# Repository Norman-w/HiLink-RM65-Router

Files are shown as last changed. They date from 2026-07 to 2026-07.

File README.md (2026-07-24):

# HiLink RM65 — 家用 WiFi 行为管理路由研究

基于海凌科 **HLK-RM65**（MT7981B + MT7976C + MT7531A，Wi‑Fi 6 AX3000 / 联发科方案）的自研路由可行性评估。  
（早期曾评估 RM68 高通方案，相关资料保留在 `docs/`、`firmware/` 供对照。）

## 结论摘要

| 问题 | 结论 |
|---|---|
| 能媲美家用 AX3000 WiFi 吗？ | **硬件档位可以**；天线/固件卸载/结构做好后接近同级成品 |
| 只适合研究吗？ | **否**；规格定位含家用路由/Mesh/网关 |
| 适合重度行为管理吗？ | **单独不够**（256MB + 双 A53）；策略建议上移 |
| Mac mini + AP 怎样？ | **算力与策略远强**；WiFi 靠专业 AP，勿用 Mac 内置无线当主 AP |

详见：

- [docs/评估报告-家用WiFi行为管理可行性.md](docs/评估报告-家用WiFi行为管理可行性.md)
- [docs/架构-MAC分流旁路分析.md](docs/架构-MAC分流旁路分析.md) — RM68 轻转发 + MacBook 旁路分析

## 资料

### HLK-RM65（主资料）

官方下载页：https://h.hlktech.com/Mobile/download/FDetail/257.html  
清单：`docs/download-manifest-rm65.json`

| 文件 | 说明 |
|---|---|
| `docs/HLK-RM65-规格书-V1.31.pdf` | 产品规格书 |
| `docs/HLK-RM65结构器件规格书.zip` | BTB / 产品图 / 表贴螺柱 |
| `docs/RM65封装尺寸.pdf` | 模组封装尺寸 |
| `docs/HLK-RM65尺寸图.png` | 尺寸图（含安装孔标注） |
| `docs/HLK-RM65-KIT-V1.0.zip` | 开发套件原理图与 PCB |
| `docs/HLK-RM65-KIT-V1.0-原理图.pdf` | KIT 原理图 PDF |
| `docs/HLK-RM65-KIT-Dimension.PcbDoc.zip` | KIT 尺寸标注 PCB（外壳开孔关键） |
| `docs/RM65编译资料.pdf` | 编译资料 |
| `docs/extracted/` | 已解压与文本提取 |

### HLK-RM68（对照保留）

官方下载页：https://h.hlktech.com/Mobile/download/FDetail/348.html

| 文件 | 说明 |
|---|---|
| `docs/HLK-RM68-规格书-V1.02.pdf` | 产品规格书 |
| `docs/HLK-RM68-结构件规格书.zip` | BTB / 屏蔽罩 / 散热片 |
| `docs/HLK-AX3000-KIT-V1.0.zip` | 开发套件原理图与 PCB |
| `firmware/README.md` | OpenWrt/SDK 下载与刷机说明 |

固件 SDK（百度）：https://pan.baidu.com/s/10omz47I9bUNruT9euDZYHQ?pwd=a9pu （`rm68-master.tar.gz` ≈3.07GB）

## 推荐架构（行为管理）

```
光猫 → Mac mini / N100（策略网关）→ 交换机 → AP（商业 AP 或 RM65 AP 模式）
```

轻量一体方案：光猫 → RM65（OpenWrt + DNS/防火墙级管控）。

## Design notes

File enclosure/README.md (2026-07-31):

# HLK-AX3000-KIT V1.0 参数化外壳

本目录是基于官方 `HLK-AX3000-KIT.PcbDoc`、到货板实测和实物照片重构的
可打印版本。板框、四个安装孔和接口 XY 采用官方数据；接口 Z、高度、外伸量、
散热片和底部焊脚净空采用用户对到货板的实测值。

## 交付文件

- `rm65_kit_enclosure.scad`：参数化主模型（含尺寸与装配断言）。
- `rm65_kit_antenna.scad`：天线孔/螺母槽/理线桥（由主文件 include）。
- `rm65_kit_shell_parts.scad`：立柱、脚垫、接口切口等共用模块。
- `build/rm65_kit_bottom.stl`：底壳，正常方向打印。
- `build/rm65_kit_top.stl`：顶壳，已自动翻转到打印方向。
- `build/rm65_kit_foot_pad.stl`：单个 TPU 脚垫，打印 4 个。
- `build/rm65_kit_top_assembly.stl`：HTML 装配预览专用，不作为打印件。
- `preview.html`：合盖、爆炸、接口和天线装配预览。
- `INTERFACE_AUDIT.md`：官方坐标与实测值审计记录。

## 已落实的尺寸

- PCB：`152.0038 × 109.0000 × 1.6 mm`。
- PCB 底面：壳底内表面上方 `4.0 mm`；可容纳约 `2.5 mm` 焊脚并留
  `1.5 mm` 余量。
- PCB 顶面：壳体坐标 `Z=8.0 mm`。
- 顶部净空：散热片自 PCB 顶面 `17 mm`，另留 `2.5 mm`。
- 外壳壁/底/顶厚：`2.4 mm`；PCB 到前/右内壁通道 `3.5 mm`。
- 左侧（杜邦座 / 网口背面）增加 `20.0 mm` 主天线装配舱；后侧仍保留
  `20.0 mm` 舱与原 5 口。外形约 `183.804 × 140.800 × 29.900 mm`。

官方四孔均为 `3.175 mm` 实体孔，板左下为坐标原点：

| 位号 | X (mm) | Y (mm) |
|---|---:|---:|
| J8 | 4.0008 | 4.0053 |
| J5 | 3.9879 | 105.0016 |
| J6 | 148.3238 | 4.0000 |
| J7 | 148.3238 | 105.0000 |

每个底壳 PCB boss 有平整承托面、`2.85 mm` 导向凸台和 `1.7 mm` M2
自攻 pilot。PCB 固定与上下壳固定是两套独立紧固件，不能共用。

## 接口开口

- 右侧：六个 RJ45 的金属壳几乎连续，使用一个连续贯穿窗口，不打印口间肋。
  RJ45 自 PCB 顶面高 `13.8 mm`、向外 `2.0 mm`，窗口上下各留 `0.4 mm`。
- 下侧：`GPIO_RST`、`SYS_RST` 两个 `3.2 mm` 细工具孔，外侧有 `6 mm`
  浅凹导向；按钮高 `4.5 mm`、向外 `0.5 mm`。
- 下侧：USB-A 从 PCB 顶面 `0.5–8.0 mm`，向外 `2.5 mm`；中心
  `X=51.0 mm`（实物尺测外口 `X=43.5–58.5 mm`）；开口
  `15.6 × 8.3 mm`，对应打印边界 `X=43.2–58.8 mm`。官方 PcbDoc
  的 `X=38.40 mm` 是封装/3D 模型插入原点，不是 USB 金属口中心。
- 下侧：12 V DC 座贴 PCB，高 `10.8 mm`、向外 `1.2 mm`；开口直径
  `11.4 mm`。壳外应保留约 `18 mm` 插头握持空间和 `35 mm` 线缆弯折空间。
- 左侧：USB-TTL Type-C 贴 PCB，高 `3.0 mm`、向外 `0.8 mm`；开口
  `10.0 × 3.8 mm`，隧道加深穿过左侧 `20 mm` 天线装配舱到达板载口。旧版
  误用了封装参考点 Y=`19.1213 mm`；官方封装外形宽 `8.636 mm`，修订后使用
  插口中心 Y=`14.7673 mm`。左侧维护针排保持封闭，不再开窗。
- 顶面靠后：九个 `3.6 mm` LED 窗，各自带 `5.4 mm` 外径的垂直隔光导管；
  建议插入 3 mm 透明导光棒或光纤，长度按打印件与 LED 的实际距离修剪。

接口前的 3.5 mm 空腔是插头通道，不是额外挡板。Type-C、USB、DC 和 RJ45
公头均从外侧窗口穿过该通道插入板载母座。
侧面接口布尔切口会继续延伸穿过顶壳定位裙边；RJ45、USB-A、DC、两个
Reset 工具孔和 Type-C 的插入路径内不会残留裙边薄片。接口以外的裙边仍保留，
用于上下壳定位和承受横向载荷。

## 天线结构

共 10 个 M6 座（后 5 + 左 5），套餐只拧 **5 根**：2.4G×2 + 5G×3。
IPX 够得着**后壁左三孔 + 左侧任意孔**；后壁右两孔留空。推荐座与倾角见
`INTERFACE_AUDIT.md` RF 表（预览「RF五天线方案」：蓝=2.4G，橙=5G，灰座=空）。

每个安装位包括：

- `6.5 mm` M6 圆形贯穿孔（M6 螺纹另留 `0.5 mm` FDM 余量）；
- 外侧 `1.0 mm` 深、Ø9 面沉，使外丝多探出约 1 mm，胶棒天线更易拧紧；
- 内侧 `8.3 mm` 对边、深 `3.2 mm` 的六角螺母槽；
- `13 × 12 mm` 内侧加厚区，底边严格止于上下壳分型面；
- 独立馈线固定桥；左/后舱按 `23 mm` 穿装包络预留。

用户实测螺纹为 M6；六角螺母边长约 `4.6 mm`、厚约 `3 mm`，折算对边约 `7.97 mm`；
默认 `8.3 mm` 螺母槽包含 FDM 装配余量。不同打印机的孔收缩不同，正式长印
前建议只切片/打印一个天线孔和螺母槽局部小样；若过紧，调整
`antenna_hole_diameter` 或 `antenna_nut_across_flats`，不要强压。

## 紧固件与脚垫

- PCB：`4 × M2×6` 盘头自攻螺钉，锁入底壳 `1.7 mm` pilot。
- 合盖：推荐 `4 × M2×20` 沉头螺钉，从外底面进入，锁入顶壳 boss。默认沉头大口
  `5.0 mm`、深 `1.8 mm`，大口朝外、向内收窄到 `2.3 mm`。螺钉长度按
  实际打印后的有效牙深选配；M2×20 约有 4 mm 的顶壳有效啮合。
- 脚垫：`rm65_kit_foot_pad.stl` 打印 4 个，推荐 TPU 95A。底壳槽直径
  `11.0 mm`、入口 `11.4 mm`、深 `1.0 mm`；脚垫直径 `11.2 mm`、总高
  `3.2 mm`，约 `2.2 mm` 外露。四槽与四个沉头工具通道完全错开。

顶壳和底壳合盖 boss 均有直接连接壳壁/壳顶的加强肋。底壳通孔柱止于
`Z=16 mm` 分型面，顶壳受牙柱从同一分型面向顶盖延伸；顶壳肋只位于壳内，
不会伸入底壳或与其干涉。顶壳内裙每侧保留 `0.30 mm` 配合间隙。
顶壳定位裙边根部另有连续环形斜肋：在 `4.0 mm` 高度内从分型定位条
向外缓慢展开，并嵌入顶壳侧壁 `0.60 mm`。裙边内侧保持竖直，不再向
壳内形成楔形尖角；分型面以下的外侧配合尺寸不变，因此仍保留原合盖间隙。

## 打印与预览

```sh
cd enclosure
./export_stl.sh
python3 server.py
```

浏览 `http://127.0.0.1:8080/preview.html`。Three.js 依赖从 unpkg 加载，首次
打开需联网。默认显示真实闭合装配；爆炸视图中的 PCB、接口、螺钉、螺母、
馈线和天线是非打印装配说明，下载区只有壳体和 TPU 脚垫。

建议 FDM 参数：0.4 mm 喷嘴、0.2 mm 层高、4 道墙、顶底至少 5 层、
20–30% 填充。底壳外底面朝下；顶壳使用已翻转的 STL。顶壳文字
`NORMAN`（11.5 mm）/ `Router V1.2.0`（7.2 mm）是贯穿镂空，保留
1.0 mm 模板连桥；两行均在前侧（下侧接口上方），NORMAN 居中、版本靠右，
避开中央通风槽。

## 仍需在首次试装时关注的风险

现有资料已足够生成直接切片的 STL，不再缺少板卡坐标或接口高度。但以下是
打印工艺公差，不应伪装成官方尺寸：

1. Ø6.5 mm 圆孔、8.3 mm 六角槽、M2 pilot 和顶壳裙边会受材料收缩与孔补偿影响；
   先做局部小样或在切片器设置孔补偿。
2. LED 导光棒不是套餐 B 已知配件；不安装时仍可透光，但亮度和串光效果需
   实机上电确认。
3. 默认结构按 M2×20 沉头螺钉提供约 4 mm 啮合；不同螺头标准与打印 pilot
   松紧仍需装配前试配。
4. 12 V 适配器极性应按适配器标签确认；RM65 模块的 3.3 V 不是 KIT 的
   外部直供电压。

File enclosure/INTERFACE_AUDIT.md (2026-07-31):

# HLK-AX3000-KIT V1.0 接口与安装坐标审计

本表记录 `rm65_kit_enclosure.scad` 的数据来源。XY/四孔以官方 PcbDoc 为准；
Z、高度和外伸量来自用户对 `HLK-AX3000-KIT V1.0 241205` 到货板的实测。

## PCB 与安装孔

- 板框：`152.0038 × 109.0000 mm`。
- J8：`(4.0008, 4.0053) mm`。
- J5：`(3.9879, 105.0016) mm`。
- J6：`(148.3238, 4.0000) mm`。
- J7：`(148.3238, 105.0000) mm`。
- 四孔实体孔径：官方 `125 mil = 3.175 mm`；焊盘约 `5.08 mm`。

用户手测约 3 mm 孔径、距相邻板边约 3.5 mm，与肉眼/卡尺精度下的官方数据
相容；模型采用官方精确值，不再使用旧版 4 mm 对称猜值。

## 接口数据

| 接口 | 官方 PCB 相对坐标 | 实测 Z/外伸 | 壳体处理 |
|---|---|---|---|
| SW1 / GPIO_RST | X=11.29 | 高4.5，外伸0.5 | 3.2工具孔+6.0浅凹 |
| SW2 / SYS_RST | X=22.03 | 高4.5，外伸0.5 | 3.2工具孔+6.0浅凹 |
| USB-A / USB2 | 官方插入原点 X=38.40；实物口 X=43.5–58.5，中心 X=51.0 | Z=0.5–8.0，外伸2.5 | 15.6×8.3贯穿窗；实测口中心相对原点 +12.6 mm |
| 12V DC / J1 | X=99.95 | 贴板，高10.8，外伸1.2 | Ø11.4贯穿孔 |
| USB-TTL Type-C / USB1 | 参考 Y=19.1213；外形中心 Y=14.7673 | 贴板，高3.0，外伸0.8 | 10.0×3.8左侧窗；采用官方封装外形中心 |
| RJ45 ×6 | Y=15.64…91.74 | 贴板，高13.8，外伸2.0 | 一个连续窗口，无口间肋 |
| LED ×9 | Y=102.06；X=15.01…64.40 | 彩色灯帽朝上 | 顶面9个Ø3.6窗+独立导光管 |

RJ3 是四联口，RJ1/RJ2 为两个单口，物理共六口。用户照片确认金属外壳之间
几乎相贴，因此打印塑料隔肋既不符合实物又会形成脆弱薄壁，已改成连续窗。

左侧 JP1/JP2/JP3/JP4/JP7 维护针排保留在壳内；用户明确不需要外部访问，
模型不再开维护窗。USB-TTL Type-C 是左侧唯一外部服务开口。

## 高度基准

- PCB 下方最高焊脚约 `2.5 mm`；模型留 `4.0 mm`。
- PCB 厚 `1.6 mm`，模型 PCB 顶面在 `Z=8.0 mm`。
- 上方最高为散热片，自 PCB 顶面 `17 mm`；模型再留 `2.5 mm`，顶盖内表面
  在 `Z=27.5 mm`。
- 组件占位和壳体孔均由同一组参数派生，不再共用旧版猜测的全局 Z=13 mm。

## 天线与电源

套餐 B 含 5 根同规格 6 dB 胶棒天线、连接线和 12 V 1 A 适配器。实测天线
接头无防转平面；实物确认是 M6 螺纹，总长约 10 mm，装外部天线后余约 5 mm，
六角螺母厚约 3 mm、边长约 4.6 mm。模型采用 Ø6.5 mm 贯穿孔、8.3 mm 对边
六角槽和内侧加厚。首版试装还确认接头必须从内向外穿装。

IPX 馈线偏短：后壁**右侧两孔够不着**，可用范围为**后壁左侧三孔 + 左侧五孔**。
壳体仍打印 10 个 M6 座；套餐只装 **5 根**（2.4G×2 + 5G×3），其余座留空不拧。

### RF 装法（编译期校验间距）

| 角色 | 壁 | 坐标 (mm) | 姿态 | 备注 |
|---|---|---:|---|---|
| 2.4G-A | 左 | Y=34 | 竖直 | 避 Type-C |
| 2.4G-B | 后 | X=100 | 竖直 | IPX 可达最远后座；与 A 异面 |
| 5G-A | 后 | X=30 | 竖直，略外展约 20° | 后左角轻微外展即可 |
| 5G-B | 后 | X=65 | 竖直 | 与 5G-A 间距 35 mm |
| 5G-C | 左 | Y=90 | 竖直 | 靠孔距做分集，不必大倾角 |

留空：后壁 X≈139 / 172；左壁 Y=55 / 72 / 128。  
目标间距：2.4G 对 ≈146 mm（>λ/2≈62.5）；5G 互距 ≥35 mm（≥λ/2≈27.5 @5.5 GHz）。  
PCB 原点 `25.9, 5.9`；Type-C 隧道加深；天线孔外侧 `1.0 mm` 面沉（Ø9）。

原理图 J1 输入网络标注 `+4.5V~18V`；套餐适配器为 12 V 1 A。RM65 模块的
3.3 V 由底板转换，不是整套 KIT 的外部直供电压。适配器极性仍应以标签为准。

## 仍非官方定值的项目

- FDM 打印后的孔收缩、裙边配合和 M2 pilot 自攻松紧。
- LED 导光棒材质、长度、亮度及串光效果。
- 合盖默认 M2×20 沉头螺钉的螺头标准与自攻松紧。

这些属于打印/装配验证，不是板卡尺寸缺口；STL 可直接进入切片器，但正式长印
前仍推荐打印天线螺母槽和 M2 pilot 的局部试配件。

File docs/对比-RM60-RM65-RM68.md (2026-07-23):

# HLK-RM60 / RM65 / RM68 对比

> 依据海凌科公开产品页与规格书摘要（非实验室实测）。信号最终仍取决于天线与固件。

## 一览

| 项目 | **RM60** | **RM65** | **RM68** |
|---|---|---|---|
| 定位 | 入门 Wi‑Fi 6 路由模组 | 家用级 AX3000（联发科） | 家用级 AX3000（高通） |
| 芯片方案 | MT7621A + MT7905 + MT7975 | **MT7981B + MT7976C + MT7531A** | **IPQ5018 + QCA8337 + QCN6102** |
| Wi‑Fi 档位 | **AX1800**（约 573+1201 Mbps） | **AX3000**（574+2402 Mbps） | **AX3000**（574+2402 Mbps） |
| 5G 频宽 | 最高约 **80 MHz** | **160 MHz** | **160 MHz** |
| CPU | 双核 MIPS @ **880 MHz** | 双核 A53 @ **1.3 GHz** | 双核 A53 @ **1 GHz** + 12 线程网络协处理 |
| 内存 / Flash | **128 MB / 16 MB** | **256 MB / 128 MB NAND** | **256 MB / 128 MB NAND** |
| 网口 | 千兆 ×5 | 千兆 ×5~6，另有 **2.5G SGMII** 能力 | 千兆 ×6（1WAN+5LAN） |
| 外置 FEM | 常规方案 | 常规高性能 | 宣传 **外挂 4× FEM** |
| 供电 | 3.3V | 3.3V（建议 ≥5A） | **5V**（建议 ≥3.5A） |
| 工作温度 | 约 -20~60℃ | -20~80℃ | -20~80℃ |
| 软件 | OpenWrt | OpenWrt | OpenWrt |
| 尺寸 | 约 60×90 mm | 60×90 mm | 60×90 mm |

## 信号谁更强？

**标称无线能力：RM65 ≈ RM68 ≫ RM60。**

- RM60 是 AX1800，5G 无 160 MHz，天花板明显更低。  
- RM65 / RM68 同属 AX3000 + 160 MHz，理论峰值同级。  
- 规格书发射功率都在「家用路由」量级（约十几～二十多 dBm）；RM68 强调 4×FEM、RM65 2.4G 也可到 ~24 dBm 档——**纸面接近，实墙表现看天线与校准，不能只看型号判输赢**。  
- 若只比「模组射频档位」：**不要选 RM60 当主力覆盖**；RM65 与 RM68 同档，需实测。

## 算力 / 做分流小程序谁更合适？

| 维度 | 更强方 | 说明 |
|---|---|---|
| CPU 主频与通用算力 | **RM65** | 1.3 GHz A53，跑 OpenWrt 用户态更宽裕 |
| 路由硬件卸载潜力 | RM68（若固件带齐 NSS）/ RM65（Filogic 生态） | 主线 OpenWrt 上高通 IPQ50xx 卸载常不完整 |
| Flash 装软件包 | **RM65 / RM68** | RM60 仅 16 MB Flash，自定义包很容易装不下 |
| 社区 OpenWrt 成熟度 | **通常 RM65（MT7981）更省心** | 联发科 Filogic 在 OpenWrt 上更常见；RM68 要盯厂商 SDK/卸载 |
| 2.5G 上行扩展 | **RM65** | 有 2.5G SGMII；RM68 规格以千兆口为主 |
| 与 KIT/资料 | 各有套件 | 你当前仓库已集中 RM68 资料 |

对「RM68 轻分流 + Mac 旁路分析」：**三款都能做用户态控 nft 规则**；更稳妥量产候选往往是 **RM65（生态）或 RM68（你已选型）**；RM60 仅适合验证概念，Flash/性能偏紧。

## 能力排序（综合）

```
家用 Wi‑Fi 吞吐/覆盖潜力：  RM65 ≈ RM68  >>  RM60
OpenWrt 二次开发省心度：    RM65  ≥  RM68  >>  RM60
内存/装包空间：              RM65 ≈ RM68  >>  RM60
性价比/入门：                RM60（但能力最弱）
```

**一句话：要信号和家用体验选 RM65 或 RM68（同档 AX3000）；RM60 明显低一档。RM65 更偏联发科生态与主频；RM68 更偏高通 + 外挂 FEM，适合你已开始的资料与 KIT 路线。**

---

## 对另一 AI「RM68 信号更强 / 工业宽温」说法的核对

| 说法 | 准确性 | 依据 |
|---|---|---|
| 两者都是 AX3000，速率 574+2402 | ✅ 正确 | 双方规格一致 |
| RM68 = IPQ5018 + QCN6102，外挂 4×FEM | ✅ 正确 | RM68 规格书写明 |
| RM65 = MT7981B @ 1.3GHz，算力更强 | ✅ 大体正确 | 主频更高，跑插件更宽裕 |
| RM68 有 12 线程 NPU，高并发更稳 | ⚠️ **有条件** | 厂商 SDK/带 NSS 卸载时成立；**主线 OpenWrt 上 IPQ50xx 常缺完整 NSS**，优势可能消失 |
| RM65 是「内置功放」、极限功率必弱于 RM68 | ❌ **不准确** | 英文页亦提到 2.4/5G PA/LNA；RM65 标称 2.4G 可达 ~24.5dBm，RM68 规格约 +23dBm 档——**不能据此断定 RM68 信号必强** |
| RM68 工作温度 -40℃~85℃ 工业级 | ❌ **错误** | **规格书 V1.02：工作 -20℃~80℃**；-40~85 是**存储**温度。营销文案「宽温 -40~85」与规格书冲突，以规格书为准 |
| RM65 工作 -20~80℃ | ✅ 与公开页一致 | 与 RM68 **工作温区同档** |
| 供电 3.3V/5A vs 5V/3.5A | ✅ 正确 | 底板电源设计不同 |

**结论：另一 AI 的芯片与算力侧写大体可用；「RM68 信号必然更强」「工业级 -40℃ 工作」不可采信。选型不能只靠 FEM 叙事。**

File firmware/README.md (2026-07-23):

# HLK-RM68 OpenWrt 固件说明

> 官方**没有**在下载中心直接挂 `.img`；固件在厂商 Gitee 指向的百度网盘 **SDK** 内，需编译生成，或向卖家索取现成 `nand-ipq5018-single.img`。

## 官方软件源

| 来源 | 链接 |
|---|---|
| Google Drive（资料 + 软件索引） | https://drive.google.com/drive/folders/1cPfJ_ET9kue43kTUIWVMKmQjL_faICfI |
| Gitee 刷机/编译说明 | https://gitee.com/shenyachuan/rm68 |
| **SDK 百度网盘（20250621）** | https://pan.baidu.com/s/10omz47I9bUNruT9euDZYHQ?pwd=a9pu （提取码 `a9pu`） |

百度网盘内实际文件（已核对）：

```text
20250621/rm68-master.tar.gz   ≈ 3.07 GB   （完整 QSDK，不是现成 .img）
```

目标刷机文件名（**需自行编译**后得到）：

```text
nand-ipq5018-single.img
```

路径（SDK 编译完成后）：`rm68-master/common/build/bin/nand-ipq5018-single.img`

**不要**刷其它机型的 IPQ5018 通用固件（分区/射频不同，易变砖）。  
网盘无现成可刷 `.img`；最快路径是：登录百度下载 SDK，或直接问店铺客服要 `nand-ipq5018-single.img`。

## 默认账号（厂商说明）

| 入口 | 地址/账号 | 密码 |
|---|---|---|
| Web | `http://192.168.1.1` | `admin` |
| SSH | `root` | `admin` |
| 串口 | 115200 8N1 | — |

（规格书曾写空密码；以 Gitee README 的 `admin` 为准，以实机为准。）

## 刷机方式 A：U-Boot + TFTP（推荐首次）

1. 电脑有线网卡静态 IP：`192.168.16.112`  
2. 网线接 RM68 底板 **WAN**  
3. TFTPd 根目录指向含 `nand-ipq5018-single.img` 的文件夹  
4. 串口上电，出现 `Hit any key to stop autoboot` 时按键进入 U-Boot  
5. 执行：

```sh
setenv ipaddr 192.168.16.123
setenv serverip 192.168.16.112
setenv bootargs console=ttyMSM0,115200n8
tftpboot nand-ipq5018-single.img
imgaddr=$fileaddr && source $imgaddr:script
```

图示见本目录 `gitee-rm68/image/`。

## 刷机方式 B：系统内 sysupgrade

设备已能 SSH 时：

```sh
# 本机
scp nand-ipq5018-single.img root@192.168.1.1:/tmp/

# 设备上
cd /tmp
sysupgrade nand-ipq5018-single.img
```

## 本仓库已缓存

- `HLK-RM68-drive/`：Drive 上的规格/结构件 + `software reference link.docx`  
- `gitee-rm68/`：官方刷机说明与截图  
- `RM68-SDK-README.md`：README 副本  

**预编译 `.img` 需你从百度网盘下载 SDK 后编译，或向海凌科/店铺客服要现成镜像。** 自动化环境无法绕过百度网盘登录验证码。

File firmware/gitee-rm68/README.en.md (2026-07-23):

# RM68

#### Description
rm68仓库，sdk太大，无法上传到git 
只有一个百度云盘的连接 ，SDK如果有更新会更换连接

#### Software Architecture
Software architecture description

#### Installation

1.  xxxx
2.  xxxx
3.  xxxx

#### Instructions

1.  xxxx
2.  xxxx
3.  xxxx

#### Contribution

1.  Fork the repository
2.  Create Feat_xxx branch
3.  Commit your code
4.  Create Pull Request

#### Gitee Feature

1.  You can use Readme\_XXX.md to support different languages, such as Readme\_en.md, Readme\_zh.md
2.  Gitee blog [blog.gitee.com](https://blog.gitee.com)
3.  Explore open source project [https://gitee.com/explore](https://gitee.com/explore)
4.  The most valuable open source project [GVP](https://gitee.com/gvp)
5.  The manual of Gitee [https://gitee.com/help](https://gitee.com/help)
6.  The most popular members  [https://gitee.com/gitee-stars/](https://gitee.com/gitee-stars/)

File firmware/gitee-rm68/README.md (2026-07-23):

# RM68

#### 介绍

#### SDK压缩包链接地址

20250621：
    通过网盘分享的文件：20250621
    链接: https://pan.baidu.com/s/10omz47I9bUNruT9euDZYHQ?pwd=a9pu 提取码: a9pu
#### 编译环境搭建

### 系统

SDK 编译环境 使用ubuntu16.04 其他版本不支持
ubuntu16.04下载地址：
    https://releases.ubuntu.com/16.04/ubuntu-16.04.7-desktop-amd64.iso
使用 virtualbox 安装
### 安装编译环境

sudo apt-get install gcc g++ binutils patch bzip2 flex make gettext pkg-config unzip zlib1g-dev libc6-dev subversion libncurses5-dev gawk sharutils curl libxml-parser-perl python-yaml ocaml-nox ocaml ocaml-findlib libssl-dev libfdt-dev  device-tree-compiler u-boot-tools autoconf libc6-i386  libgl1-mesa-dri:i386 mtd-utils libfdt-dev vim samba openssh-server git subversion flex make cmake quilt

### 编译
    tar xvf rm68-master.tar.gz     #默认解压到rm68-master目录下
    cd rm68-master/qsdk
    make V=s -j5
### 生成固件
    编译完成后， 需要使用命令 生成固件

    cd rm68-master/    #注意 执行命令前 需要进入到 SDK的根目录下
    mkdir -p common/build/ipq
    mkdir -p apss_proc/out/meta-scripts
    cp qsdk/qca/src/u-boot-2016/tools/pack.py apss_proc/out/meta-scripts/pack_hk.py
    sed -i 's#</linux_root_path>#/</linux_root_path>#' contents.xml
    sed -i 's#</windows_root_path>#\\</windows_root_path>#' contents.xml
    cp qsdk/bin/ipq/openwrt* common/build/ipq
    cp -r apss_proc/out/proprietary/QSDK-Base/meta-tools apss_proc/out/
    cp -rf qsdk/bin/ipq/dtbs/* common/build/ipq/
    cp -rf skales/* common/build/ipq
    cp -rf wlan_proc/build/ms/bin/5018.wlanfw.eval/* common/build/ipq/
    cp -rf wlan_proc/build/ms/bin/5018.wlanfw2.map_spruce_eval/* common/build/ipq/
    cp -rf wlan_proc/build/ms/bin/5018.wlanfw2.map_spr_spr_eval_cs/* common/build/ipq/
    cp -rf btfw_proc/out/IPQ5018/bin/FW_IMAGES/bt_fw_patch_* common/build/ipq
    cp qsdk/staging_dir/host/bin/ubinize common/build/ipq/
    cd common/build/
    sed "s/'''$/\n'''/g" -i update_common_info.py
    sed -i "s/os.chdir(ipq_dir)//" update_common_info.py
    sed -i -e '/update_common_info.py: 16M debug/,+5d' update_common_info.py
    sed '/packages/d;/"ipq5018_64"/d;/t32/d;/ret_prep_64image/d;/Required/d;/skales/d; /nosmmu/d;/os.system(cmd)/d;/os.chdir(ipq_dir)/d;/atfdir/d;/noac/d;/singleatf/d;/bl31.mbn/d;/bin_atf/d;/ret_pack_64image/d;/list_out_64_single/d;/list_out_64_apps/d;/dict_64_bit_single/d;/dict_64_bit_apps/d;/list_out_debug/d' -i update_common_info.py
    export BLD_ENV_BUILD_ID=LM256;python update_common_info.py

    执行完成后，会在common/build/bin 目录下生成几个文件
    其中nand-ipq5018-single.img 是匹配我们的硬件的固件

### 升级
    升级有两种方式
## 通过uboot升级
    在uboot下升级
    环境准备：
        电脑需要设置静态IP ： 192.168.16.112
        电脑的网口接RM68底板的WAN口
        电脑打开tftpd软件，目录选择文件nand-ipq5018-single.img所在目录
    RM68底板的调试串口位置：
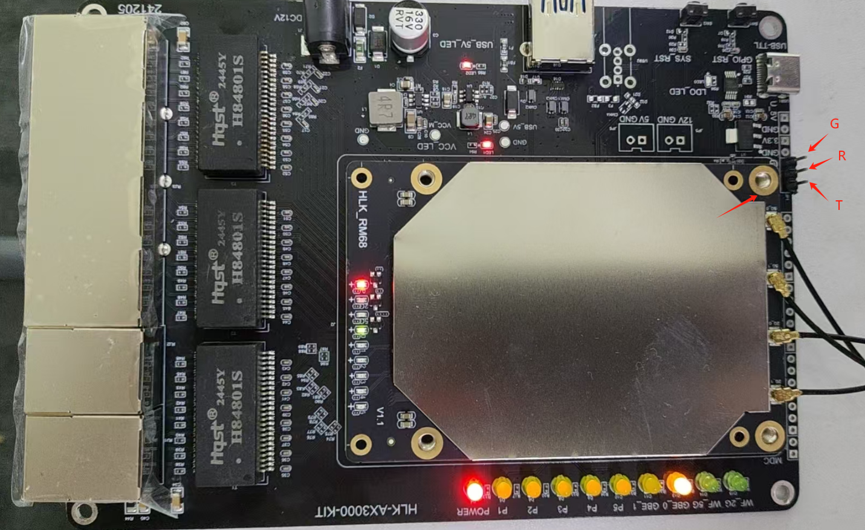
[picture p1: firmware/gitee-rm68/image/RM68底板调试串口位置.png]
底板串口位置

    默认串口波特率 ： 115200

    这里通过mobaxterm 终端工具演示：
    上电启动 在 串口输出 Hit any key to stop autoboot 倒计时时 按任意键 进入到uboot命令行
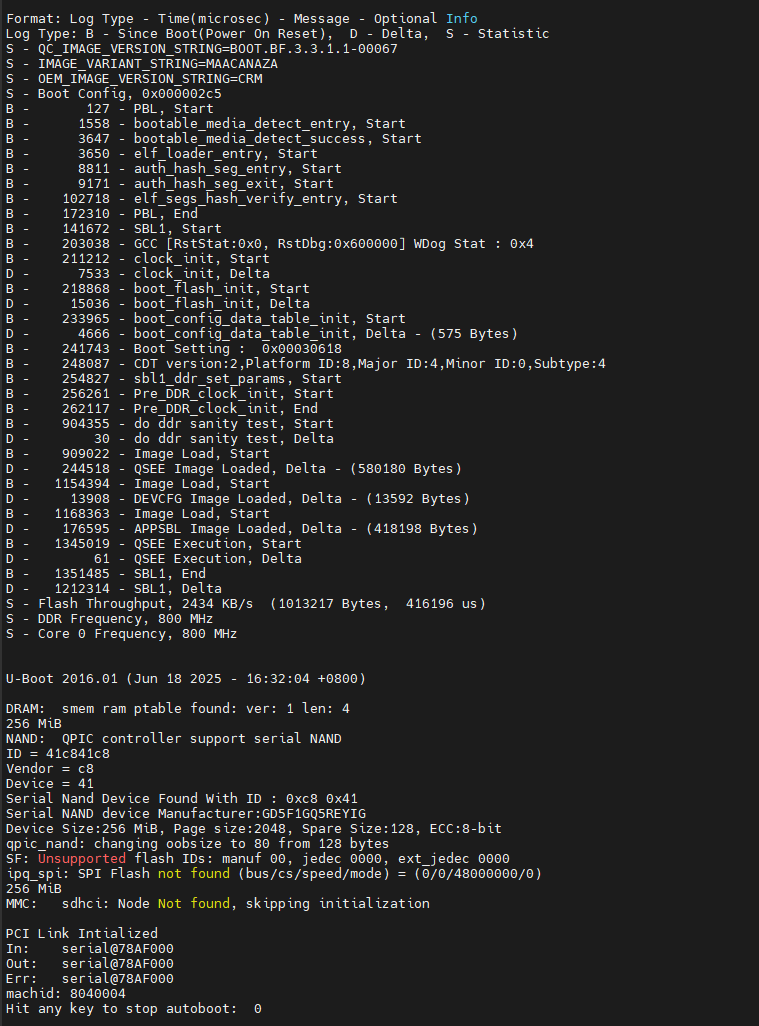
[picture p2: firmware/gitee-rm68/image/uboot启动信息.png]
uboot启动信息

    输入命令：
        #下载固件：
        setenv ipaddr 192.168.16.123
        setenv serverip 192.168.16.112
        setenv bootargs console=ttyMSM0,115200n8
        tftpboot nand-ipq5018-single.img
        固件下载过程：
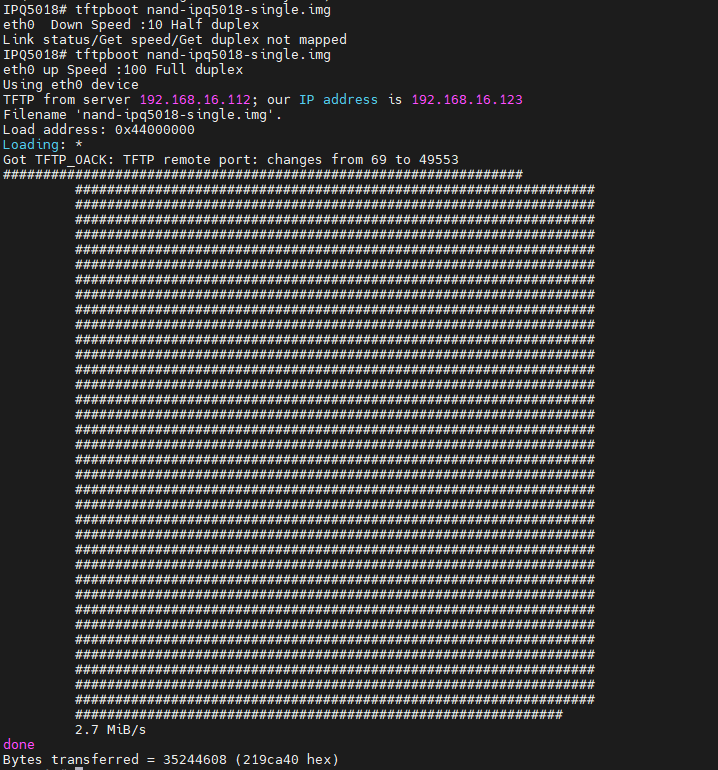
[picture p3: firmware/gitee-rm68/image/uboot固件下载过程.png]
uboot下固件下载过程

        更新固件：
        imgaddr=$fileaddr && source $imgaddr:script
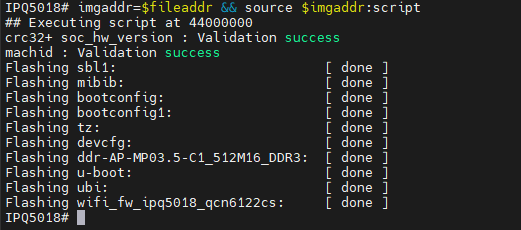
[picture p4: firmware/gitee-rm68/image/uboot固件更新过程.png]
uboot下固件更新过程


## 通过固件升级
    固件启动成功后
    通过scp上传固件
    这里使用mobaxterm 的scp功能
    使用ssh 连接到 设备 
    用户名: root
    密码: admin
    连接成功后 修改scp的目录到/tmp下
    拖拽固件到设备上
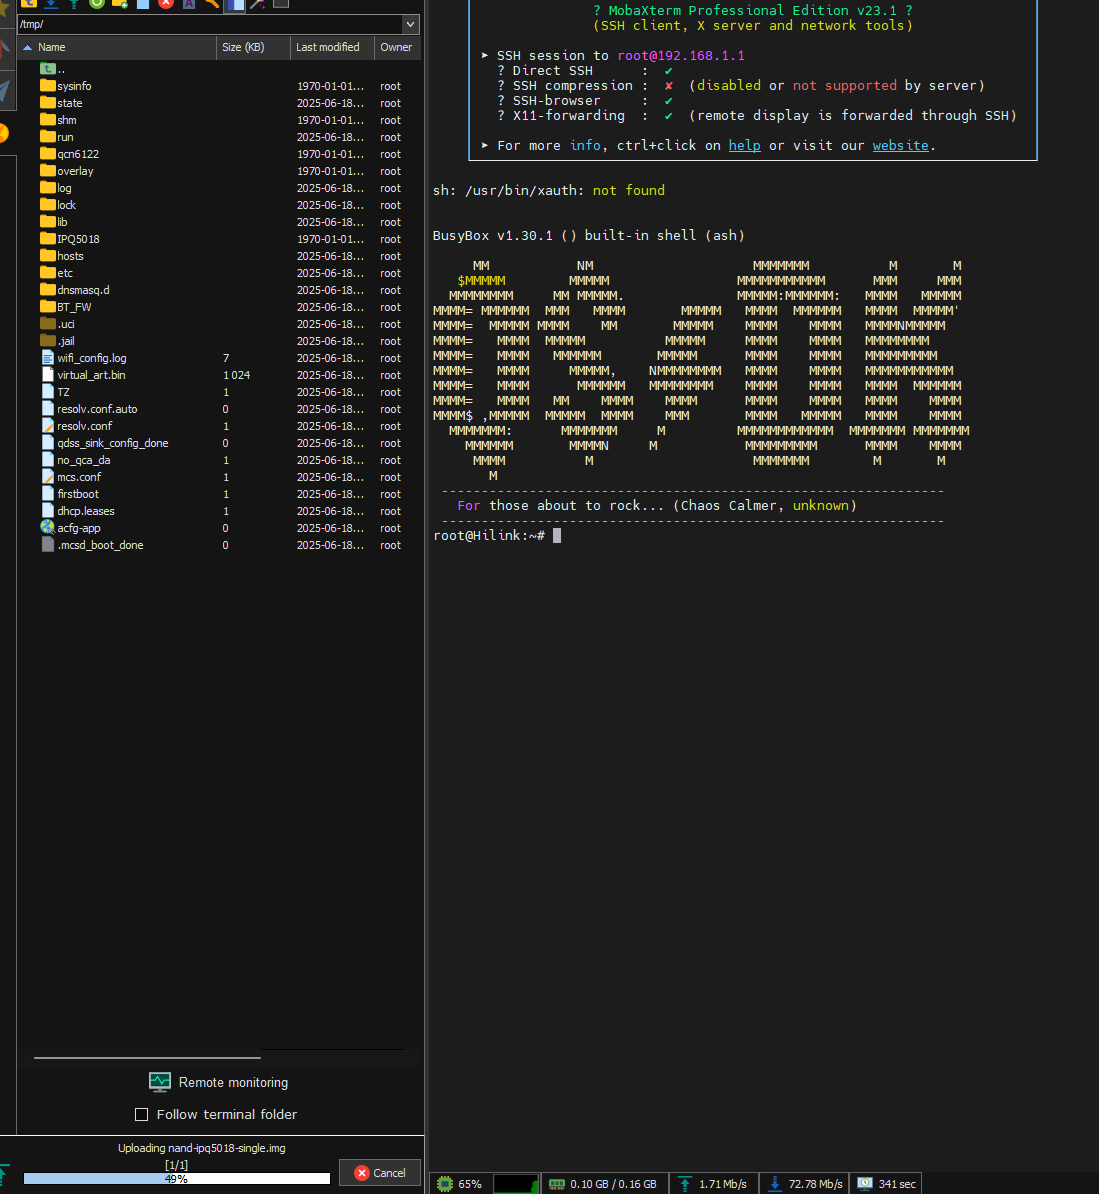
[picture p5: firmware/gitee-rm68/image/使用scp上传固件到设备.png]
scp上传固件


    固件上传成功后，使用sysupgrade命令 升级固件
    cd /tmp/
    sysupgrade nand-ipq5018-single.img

### 功能描述
## web
    默认管理地址：192.168.1.1
    web 默认密码：admin
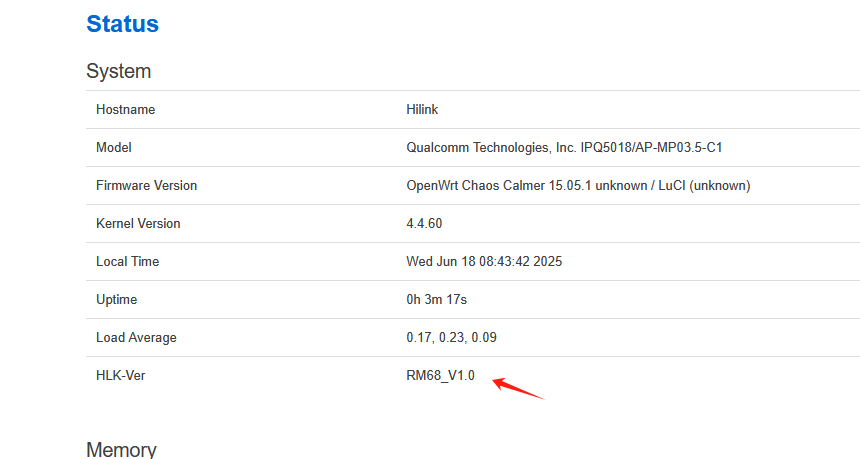
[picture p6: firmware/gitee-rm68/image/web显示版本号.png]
版本号显示


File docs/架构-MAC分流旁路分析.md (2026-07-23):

# 架构：RM68 轻转发 + MacBook 旁路分析（按 MAC 匹配）

> 目标：平时 RM68 当正常家用路由；仅对指定 MAC（手机/平板/电子相册/电视等）在 Mac 在线时把流量旁路到 macOS 做检测/过滤；Mac 离线则 **fail-open 放行**。  
> 结论：**方向正确，能避免把重度分析压垮 RM68**；但要实现「广告/非法请求过滤 + 视频设备不卡」，必须分层，不能把所有包无脑全量 MITM。

---

## 1. 你的想法对不对？

**对，而且这正是「控制面轻、分析面重」的正确拆分。**

| 角色 | 职责 | 负载 |
|---|---|---|
| RM68 / OpenWrt | 正常路由 + **按 MAC 打标/分流** + 健康检查 + fail-open | 轻（规则匹配 + 转发） |
| MacBook（有线挂 LAN） | DPI / 广告域名 / 非法 URL / 调试抓包 / 策略决策 | 重 |
| 未匹配 MAC 的设备 | 走 RM68 默认转发，完全不经 Mac | 零额外开销 |

这样：

- RM68 **不会**被 Suricata/机器学习/完整 HTTPS 解密拖垮。  
- 平时无匹配、或 Mac 离线 → 就是普通路由器。  
- 调试特定设备时再「挂上分析器」。

---

## 2. 推荐数据路径（不要做成「包到用户态再回送」）

错误直觉：每个包在 OpenWrt 用户态读出来 → TCP 发给 Mac → Mac 再发回来。  
这会把 RM68 **用户态拷贝**打满，视频流量很容易卡。

正确做法：**内核策略路由 / 透明代理，Mac 做 middlebox**。

```
                    ┌─ Mac 离线 / 心跳失败 ─┐
客户端(指定MAC) ──► RM68 ──┤                      ├─► 直连 WAN（fail-open）
                    └─ Mac 在线 ────────────┘
                              │
                              ▼
                     有线到 MacBook
                     (透明代理 / 网关旁路)
                              │
                     分析：放行 / 阻断 / 改 DNS
                              │
                              ▼
                            WAN
```

### 2.1 两种模式（建议都做）

**模式 A — 旁路观测（调试首选，几乎不拖垮）**

- OpenWrt：`tee`/`nflog`/端口镜像，把匹配 MAC 的包 **复制一份** 给 Mac。  
- 主路径仍直接出 WAN，**零回程**。  
- 适合：看电子相册/电视到底请求了哪些广告域名、非法 CDN、诡异 UDP。  
- 不能主动拦截（只看不拦）。

**模式 B — 串接过滤（要拦广告/非法请求）**

- OpenWrt：对匹配 MAC 做 **policy routing** 或 **透明代理 REDIRECT/TPROXY**，下一跳指向 Mac。  
- Mac 跑：`mitmproxy` / `Clash`/`sing-box` / `Squid` + 规则库，或自研分析服务。  
- 决策后从 Mac 再出网（Mac 需双接口或策略 NAT），或回 RM68 指定出口。  
- Mac 心跳失败 → RM68 **立刻撤规则**，流量直通。

日常建议：**默认 A；需要过滤时对少量设备开 B。**  
视频大流量设备优先 DNS/SNI 级拦截，避免全量解密。

---

## 3. 「外接件装在 MacBook」怎么理解

MacBook 侧需要的是 **稳定、低延迟的有线旁路口**，不是让 Mac 当 Wi‑Fi AP。

| 外接形态 | 说明 |
|---|---|
| USB‑C / Thunderbolt 千兆或 2.5G 网卡 | 最实用；插 RM68 的 LAN |
| 扩展坞双网口 | 一口进（来自 RM68 分流）、一口出（可选独立上行） |
| 纯 Wi‑Fi 连 RM68 | **不推荐**做串接主路径（抖动大、易环路、睡眠断链） |

OpenWrt 侧小软件只做三件事：

1. **设备集合**：监视 MAC 列表（可 Web/UCI 配置）。  
2. **Mac 存活探测**：对 Mac 的旁路 IP 做 TCP/HTTP 心跳（如每 2s）。  
3. **装/卸规则**：在线则挂 nftables/pbr；离线则清空（fail-open）。

不必在 RM68 上做深度解析。

---

## 4. 会不会拖垮 RM68？

| 场景 | RM68 压力 | 说明 |
|---|---|---|
| 无匹配设备 / Mac 离线 | ≈ 普通路由 | 理想态 |
| 仅 DNS/域名规则过滤 | 很低 | `dnsmasq`/`nft set` 拦截广告域 |
| 匹配 MAC + 内核策略路由到 Mac | **中低** | 转发在内核，可接受 |
| 匹配 MAC + OpenWrt 用户态逐包转发 | **高，易拖垮** | 避免 |
| 全屋设备全量 HTTPS MITM | 高（在 Mac）且设备难装证书 | 不适合电子相册/电视 |

视频设备（4K 拉流）若走模式 B 全流量串接：瓶颈在 **Mac 代理吞吐与延迟**，不是 RM68 CPU——Mac 睡着或 USB 网卡不稳会卡播，所以 **fail-open 必须快（秒级）**。

---

## 5. 广告 / 非法请求：能滤到什么程度？

| 手段 | 对手机/平板 | 对电子相册/电视 | 要不要 MITM |
|---|---|---|---|
| DNS 黑洞（广告域名列表） | 很好 | **很好（首选）** | 否 |
| 阻断已知广告 IP / CDN | 好 | 好 | 否 |
| TLS SNI / HTTPS 明文 ClientHello 域名 | 较好 | 较好 | 否 |
| 完整 HTTPS 解密 | 需装 CA；App 可能证书固定 | **多数装不了 CA** | 是 |
| QUIC/HTTP3 | 需阻断 UDP/443 迫降 TCP 或放行 | 同上 | 复杂 |

**现实路径（推荐落地顺序）：**

1. **DNS 过滤 + 域名/SNI 黑名单**（解决 80% 广告与追踪）。  
2. 调试期用模式 A 抓包，把「电子相册真实请求」沉淀成规则。  
3. 仅对「你能装信任证书的手机/平板」开 HTTPS MITM。  
4. 电视/相册：**不要**指望完整解密；用 DNS/IP/SNI + 偶发抓包分析。

「非法请求」若指木马回连/异常域名：旁路观测 + 威胁情报域名列表即可；若指内容审查级 DPI，成本陡增且对加密流量仍受限。

---

## 6. Fail-open 逻辑（必须做成状态机）

```
状态: IDLE（直通） / ACTIVE（分流到 Mac） / DEGRADED（探测失败宽限）

心跳 OK 且 存在匹配 MAC 会话需求 → ACTIVE
心跳 N 次失败（如 3×2s）→ DEGRADED → 立即卸规则 → IDLE（全部放行）
心跳恢复 → 再挂规则（可延迟 5s 防抖）
```

注意：

- 卸规则要用 **原子替换 nft set / 整链 flush**，避免半中间状态把连接打坏。  
- 正在播放的长连接：从 ACTIVE→IDLE 可能闪断一次，可接受；比「Mac 挂了全家断网」好。  
- MacBook 合盖睡眠 = 离线，必须 fail-open（或外接电源 + 防睡眠策略）。

---

## 7. 和「平时当正常路由」是否冲突？

**不冲突。** 条件：

1. 默认策略：无 MAC 命中 → 零旁路规则。  
2. 旁路口只服务「分析 VLAN 或专用网段」，避免 Mac 被别的设备当网关误用。  
3. 非目标设备 DHCP 正常、Wi‑Fi 体验与现在评估报告一致（AX3000 家用档）。  
4. 分析软件崩溃不影响路由（心跳失败即直通）。

---

## 8. 推荐实现栈（务实）

### OpenWrt（RM68）

- `nftables`：`ether saddr` 匹配 MAC set。  
- `pbr` 或自写小脚本：把命中流量指到 `macbook` 接口/网关。  
- 可选：DNS 级 `nft set` 广告域（不经 Mac 也能拦）。  
- 自研 `hlk-divertd`：心跳 + 装卸载规则（几十 KB 级，别搞重框架）。

### macOS

- 有线网卡固定 IP，如 `192.168.1.2`。  
- 分析服务监听透明代理端口（或作为该网段网关）。  
- 规则引擎：广告 host 列表 + 自建「设备指纹 → 允许域名」。  
- 调试 UI：按设备看请求时间线（电子相册特别有用）。

### 外接件

- 第一版：成品 USB‑C 网卡即可验证架构。  
- 以后再做成「专用旁路盒」（双网口小配件），逻辑不变。

---

## 9. 路径是否正确？一句话

**正确：RM68 只做「认 MAC + 健康检查 + 内核分流/直通」，MacBook 做检测分析与过滤决策；离线放行。**  

要补上的关键修正：

1. 用 **内核分流**，不要用户态逐包转发。  
2. 过滤以 **DNS/SNI/IP 名单** 为主，全量 HTTPS MITM 只对可控设备。  
3. 视频/相册调试先用 **旁路镜像（模式 A）**，再对需要拦截的开串接（模式 B）。  
4. Fail-open 做成秒级状态机，Mac 睡眠不得导致断网。

这样平时就是正常路由器；插上 MacBook 外接网卡并打开分析软件时，才对指定设备进入「监控/过滤模式」。

---

## 10. 「分流在内核」要不要改 OpenWrt / 自研内核？

### 一句话

**默认不需要改内核，也不需要「先装自研内核再装 OpenWrt」。**  
OpenWrt = 内核 + rootfs 的完整系统；分流用的是系统里**已有的** netfilter / 路由子系统，你只要装软件包、写配置/小守护进程。

### 三层分别做什么

```
┌─────────────────────────────────────────────┐
│  你开发的：hlk-divertd / LuCI / 配置脚本      │  ← 用户态（心跳、装卸载规则）
├─────────────────────────────────────────────┤
│  OpenWrt 软件包：firewall4, pbr, dnsmasq…   │  ← 仍用户态，调用内核接口
├─────────────────────────────────────────────┤
│  Linux 内核（随 OpenWrt 一起烧录）            │  ← 真正转发包（nft / ip rule）
└─────────────────────────────────────────────┘
```

| 做法 | 要不要重编内核 | 要不要重烧整机 | 适用 |
|---|---|---|---|
| UCI/`nft`/ `pbr` 配规则 + 自写用户态守护进程 | **否** | 通常 **否**（opkg/自定义 ipk 即可） | **本方案首选** |
| 启用某个未打开的内核选项（极少见） | 要编 OpenWrt 内核 | 要刷含新内核的固件 | 缺 `TPROXY` 等配置时 |
| 自写 `.ko` 内核模块 | 针对该内核编译模块 | 可只装 ko，或打进固件 | 现有 nft/路由不够用时（本需求基本不需要） |
| 完全自研内核，再「旁边」装 OpenWrt | — | — | **不可行/无意义**：不能当两个互不影响的系统叠着装 |

### 和「两个互不影响」的关系

- **不是**两套 OS 并排：不能先刷一个裸内核，再刷一个不影响它的 OpenWrt。  
- **是**一层：厂商或你编译的 **OpenWrt 固件**里已经带好内核；你的分流逻辑是 **OpenWrt 之上的应用**，和 Wi‑Fi/路由共存，平时不开规则就等于普通路由。  
- MacBook 侧软件与 RM68 **完全独立**；只有 LAN 上的 IP/心跳和分流下一跳有关系。

### 推荐落地顺序

1. 用海凌科提供的 OpenWrt 能开机、当路由。  
2. 确认带 `nftables`（firewall4）和策略路由；缺什么用 `opkg` 或编一个 **只含软件包的自定义固件**（多数情况仍不用改内核源码）。  
3. 开发用户态 `hlk-divertd`：探测 Mac → `nft add/flush` 或调 `pbr`。  
4. 只有实测发现内核缺特性时，再在 OpenWrt 构建系统里改 `kernel_menuconfig` 重新出固件——那是例外，不是起点。

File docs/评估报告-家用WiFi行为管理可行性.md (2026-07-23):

# HLK-RM68 家用 WiFi 行为管理路由器可行性评估

> 资料来源：海凌科官方规格书 V1.02（2025-04-02）、AX3000-KIT 原理图、结构件规格、官网产品页  
> 评估日期：2026-07-23  
> 结论先行：**射频/吞吐硬件档位可对标主流家用 AX3000；深度行为管理更适合「x86/Mac 网关 + 专业 AP」架构。RM68 适合做家用级无线接入与轻量策略，不适合单独承担重度 DPI。**

---

## 1. 产品定位与硬件能力（规格书摘要）

| 项目 | 规格 |
|---|---|
| 型号 | HLK-RM68 |
| 芯片 | **IPQ5018 + QCA8337 + QCN6102** |
| Wi‑Fi | Wi‑Fi 6 AX3000：2.4G **574 Mbps** + 5G **2402 Mbps**（支持 160 MHz） |
| CPU | 1 GHz 双核 Cortex‑A53 + 12 线程网络协处理器（厂商宣称可卸载 Wi‑Fi） |
| 内存/闪存 | **256 MB DDR3** / **128 MB NAND** |
| 有线 | 千兆 ×6（WAN×1 + LAN×5） |
| 扩展 | USB 3.0 / PCIe 2.0（引脚复用） |
| 天线 | I‑PEX 一代 ×4，外挂 **4× FEM** |
| 发射功率（摘录） | 2.4G 最高约 **+23±2 dBm**；5G AX 约 **+19±2 dBm** |
| 软件 | **OpenWrt**，Web 升级；默认 `192.168.1.1` / `root` / 空密码 |
| 供电 | 5V，建议 ≥3.5A；平均功耗约 4W；持续发射约 1.5A |
| 尺寸/温宽 | 60×90 mm；工作 **-20℃~80℃** |
| 厂商定位 | 家用路由、Mesh 节点、网关；智能家居/工业物联模组 |

这不是「玩具级开发板」，而是**与市售 AX3000 家用路由同档的高通路由 SoC 模组**。开发套件（HLK-AX3000-KIT）提供完整底板、RJ45、电源/LED、BTB 120P，可直接做样机验证。

---

## 2. 能否媲美家用路由器的 WiFi 质量与性能？

### 2.1 可以达到「家用 AX3000 中档」的前提

**硬件层面：可以。**

- 同平台家用机（如部分小米/红米 AX3000 系列、IPQ5018 方案）理论速率同为 AX3000，5G 160 MHz、OFDMA、1024‑QAM 能力一致。
- 外挂 4 颗 FEM + 规格书中的发射功率/灵敏度，说明厂商按「家用/Mesh」覆盖目标做了功放，不是仅适合实验室短距联调的裸板。
- 6 个千兆口对家庭有线回传、IPTV、NAS 足够。

**实际 WiFi 体验取决于你补齐的「消费级整机工程」：**

| 因素 | 家用成品路由 | RM68 自研 |
|---|---|---|
| 天线设计/摆位/增益 | 厂家调校完成 | **你自己负责**（I‑PEX 外接天线选型决定生死） |
| 射频校准/功率表 | 出厂校准 | 需验证是否有完善校准固件 |
| 散热/屏蔽 | 结构件已优化 | 需按结构件规格做屏蔽罩+散热片 |
| 驱动/卸载 | 原厂固件常有 NSS/加速 | **主线 OpenWrt 上 IPQ50xx 常缺完整 NSS Wi‑Fi offload**，吞吐可能明显低于 PHY 标称 |
| Mesh/漫游体验 | App + 私有协议成熟 | OpenWrt 可做 802.11k/v/r，但体验打磨成本高 |

**结论（WiFi 本身）：**

- **不是「只适合研究、达不到家用」**——硬件档位就是家用 AX3000。
- **也不是「开箱即媲美小米/华为」**——天线、结构、固件卸载、校准不到位时，信号和实速会明显掉档。
- 做好天线+散热+（厂商 SDK 或带加速的 OpenWrt 分支）后，**单层/中小户型可以做到接近同价位成品 AX3000**；大户型仍建议多 AP/Mesh，与成品路由一样。

### 2.2 做「行为管理路由器」时的真实瓶颈

「WiFi 行为管理」通常包含：应用识别、URL/DNS 过滤、分时段、分设备策略、流量审计、家长控制、可选 DPI/IDS。

| 能力 | RM68 适合度 | 说明 |
|---|---|---|
| 基础路由/NAT/防火墙 | ★★★★☆ | OpenWrt + 千兆口够用 |
| DNS 过滤 / AdGuardHome 轻量 | ★★★☆☆ | 256MB 内存紧张，需精简 |
| SQM/CAKE 千兆整形 | ★★☆☆☆ | 双 A53@1GHz 吃力，常见只能稳住数百 Mbps 级 |
| 深度 DPI / 应用层识别 | ★☆☆☆☆ | CPU/内存不足，易拖垮整机吞吐与时延 |
| VPN（WireGuard）中等负载 | ★★★☆☆ | 轻量可行；高强度并发吃紧 |
| 多用户高并发 + 策略日志 | ★★☆☆☆ | 内存是硬伤 |

**因此：RM68 适合「家用无线 + 轻量策略网关」；不适合作为重度行为分析一体机。**

---

## 3. 三种架构对比：RM68 一体 / Mac mini+AP / 混合

### 方案 A：RM68 一体机（路由 + WiFi + 轻量策略）

```
光猫 —— RM68(OpenWrt) —— WiFi客户端 / 有线设备
              └─ 轻量：DNS过滤、防火墙、简单家长控制
```

- **优点**：成本低、功耗低（~4W）、体积小、开发链路短、和成品家用路由最像。  
- **缺点**：行为管理深度有限；WiFi 体验强依赖你的天线与固件。  
- **适合**：产品化「带基础管控的家用路由」、验证射频与 OpenWrt 定制。

### 方案 B：Mac mini 做网关 + 独立 AP（推荐做重度行为管理）

```
光猫 —— Mac mini(路由/防火墙/DPI/策略) —— 交换机 —— AP(s) —— WiFi
```

| 维度 | Mac mini 网关 | 独立 AP（如 UniFi / Omada / OpenWrt AP） |
|---|---|---|
| 路由/DPI/审计算力 | **极强**（Apple Silicon） | 不负责 |
| WiFi 信号与漫游 | **不要用 Mac 自带 WiFi 当 AP** | **专业 AP 明显更好**（天线、功率、信道、802.11k/v/r） |
| 稳定性 | 高（注意散热与 UPS） | 高 |
| 功耗/噪音/成本 | 明显高于模组方案 | AP 额外成本 |
| 家用体验 | 策略强、WiFi 取决于 AP | 覆盖/漫游可做到优于一体路由 |

要点：

1. **Mac mini 的竞争力在「有线侧智能」**，不在无线射频。  
2. Mac 当无线热点：客户端芯片、发射功率、多用户调度、DFS/信道管理都远不如专用 AP，**不适合作为家用主 AP**。  
3. 行为管理（HTTPS SNI/DNS、代理、容器化审计、机器学习识别等）放在 Mac mini 上最合理。  
4. WiFi 质量对比结论：**Mac mini + 好 AP ≫ 普通家用一体路由的管理能力；WiFi 信号 ≈ 取决于 AP，通常可优于 RM68 单板（若 AP 选得好、布点合理）。**

### 方案 C：混合（推荐产品/研究兼顾）

```
光猫 —— Mac mini / N100 小主机(策略网关)
              │
              ├── 有线到 RM68（设为 AP / Mesh 节点）
              └── 或有线到商业 AP
```

- **策略与算力**：Mac mini（或 N100）  
- **无线接入**：RM68 或商业 AP  
- **好处**：行为管理不拖累 WiFi；RM68 专注做「家用级无线接入模组」验证；以后可替换成多 AP。

---

## 4. 信号与性能对比（定性）

| 指标 | 主流家用 AX3000 成品 | RM68 自研（做好天线） | Mac mini 自带 WiFi | Mac mini + 天花板 AP |
|---|---|---|---|---|
| 5G 近场吞吐 | 高（常 800Mbps~1Gbps+） | 可达同级* | 中等偏下 | 高～很高 |
| 穿墙/覆盖 | 中～好 | 取决于天线/FEM 落地 | 差～中 | **最好（布点）** |
| 多终端并发 | 好 | 中～好* | 差 | 好～优秀 |
| 漫游 | Mesh 成熟 | 需自研 | 无 | **商业 AP 成熟** |
| 行为管理深度 | 厂商封闭/浅 | 轻量 OpenWrt | 很强 | **很强** |
| 功耗 | 低 | **很低** | 中 | 中高 |
| 开发自由度 | 低 | **高** | 高 | 高 |

\* 取决于是否有可用的硬件卸载固件；纯主线 OpenWrt 可能打不满标称。

---

## 5. 明确结论（回答你的核心问题）

### Q1：RM68 能不能跟家用路由器性能媲美？

**能，但条件是：把它当「家用 AX3000 路由主板」做完工程，而不是当实验板裸跑。**

- 芯片、FEM、网口、协议档位已经对标家用 AX3000。  
- WiFi「质量」差在天线、结构、校准、驱动加速，不差在「是不是开发模组」这个身份。  
- 若目标是「家里日常用、接近小米 AX3000 体验」——**可行**。  
- 若目标是「无工程投入、开箱就超旗舰」——**不现实**。

### Q2：是不是只适合开发研究、不适合家用？

**不是「只适合研究」。** 规格书明确写了家用路由/Mesh/网关场景。  
但若你要做的是**重度 WiFi 行为管理**，单靠 RM68 **算力与内存不够家用重度场景**，这时它更适合作为：

- 无线接入板（AP 模式），或  
- 轻量策略一体路由；  

重度分析应上移到 Mac mini / 小主机。

### Q3：Mac mini + AP 信号和性能怎么比？

- **信号与无线体验**：Mac mini+优质 AP **通常优于** 任何单台一体路由（含 RM68），因为 AP 可优位置部署、天线与漫游栈更专业。  
- **路由与行为管理性能**：Mac mini **远强于** RM68。  
- **不要**用 Mac mini 内置 WiFi 充当全家 AP。

---

## 6. 建议的落地路径

### 阶段 1：验证「家用 WiFi 能不能打」（1–2 周）

1. 使用 AX3000-KIT 底板 + 规格书推荐供电（5V/≥3.5A，纹波≤50mV）。  
2. 选用合格双频天线（注意 160 MHz 与 MIMO 布局）。  
3. 对照测试：同位置 vs 一台成品 AX3000 —— iperf3、覆盖热图、20+ 终端并发。  
4. 分别测：厂商 OpenWrt 镜像 vs 自编译主线（看 NSS/加速差异）。

### 阶段 2：验证「行为管理放哪」

1. RM68 上只跑：DNS 过滤、基础防火墙、简单时段策略。  
2. 同一套策略在 Mac mini（旁路或网关）上加重 DPI/审计，对比延迟与 CPU。  
3. 决策：产品一体（轻量）还是网关+AP（重度）。

### 阶段 3：产品化选型

| 产品目标 | 推荐架构 |
|---|---|
| 低成本家用管控路由 | **RM68 一体** + 精简 OpenWrt 策略 |
| 家庭/小办公室深度行为管理 | **Mac mini（或 N100）网关 + AP**；RM68 可作自研 AP |
| 研究射频/OpenWrt/模组二次开发 | **RM68 + KIT** 为主 |
| 大户型覆盖 | 任一网关 + **多 AP**（别指望单模组硬刚） |

---

## 7. 风险与注意点

1. **256MB 内存**：装完整 AdGuard + 统计 + VPN + 日志很容易 OOM，策略包必须裁剪。  
2. **OpenWrt/IPQ50xx 卸载**：社区已知 ath11k 在缺 NSS 时吞吐远低于 PHY；产品级性能要以实测为准。  
3. **安全**：出厂默认空密码，量产必须改。  
4. **USB3 / PCIe 复用**：外挂 5G 模组或加速卡需看引脚复用与供电。  
5. **合规**：发射功率、信道、DFS 需按目标市场认证（家用产品化绕不开）。  
6. **Mac mini 网关**：需双网口（或 USB‑C 千兆/2.5G 网卡）、建议有线回传 AP，并考虑断电续航。

---

## 8. 本仓库资料清单

```
docs/
├── HLK-RM68-规格书-V1.02.pdf
├── HLK-RM68-结构件规格书.zip
├── HLK-AX3000-KIT-V1.0.zip
├── download-manifest.json
├── extracted/
│   ├── HLK-RM68-规格书-V1.02.txt          # 规格书全文提取
│   ├── HLK-AX3000-KIT-原理图.txt
│   ├── kit/                               # Altium 工程 + 原理图 PDF
│   └── mechanical/                        # BTB/屏蔽罩/散热片
└── 评估报告-家用WiFi行为管理可行性.md      # 本文
```

官方资料页：https://h.hlktech.com/Mobile/download/FDetail/348.html

---

## 9. 一句话决策

- **要家用级 WiFi 体验**：RM68 硬件够格，关键在天线/固件/结构，不是「开发板天生不行」。  
- **要强行为管理**：用 **Mac mini（或同等 x86）做脑，AP（可自研 RM68）做嘴**；不要让 RM68 既扛无线又扛重度 DPI。  
- **研究 + 未来产品化**：先用 KIT 把无线打到成品 AX3000 的 80%+，再决定策略跑在模组上还是上移到 Mac mini。

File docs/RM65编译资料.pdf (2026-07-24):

Git 链接：https://gitee.com/shenyachuan/rm65

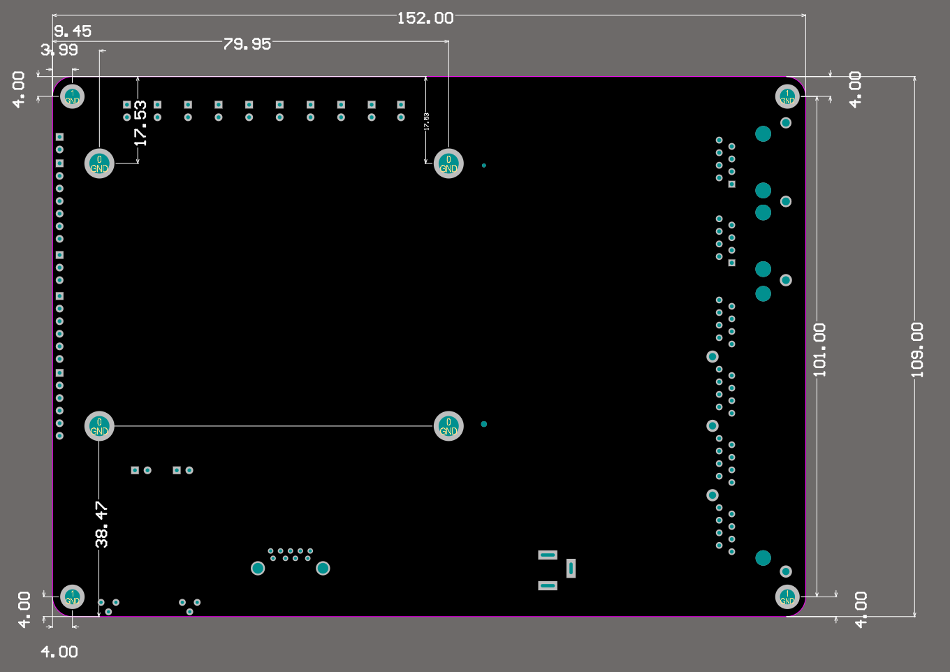
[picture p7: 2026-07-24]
docs/extracted/HLK-RM65尺寸图.png

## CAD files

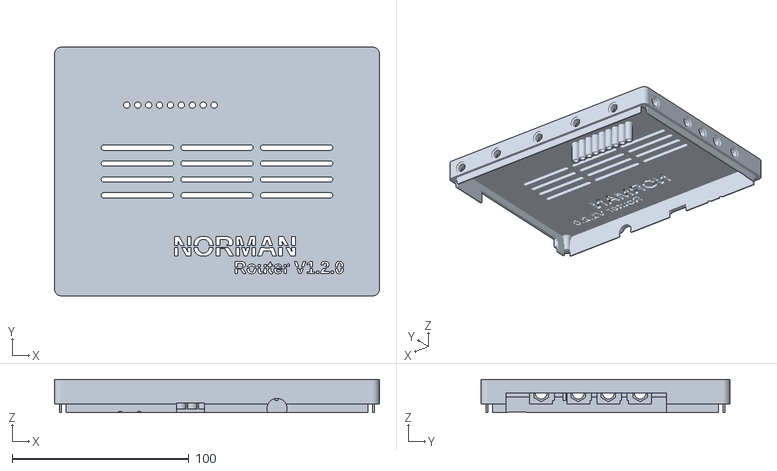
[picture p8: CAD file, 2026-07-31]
enclosure/build/rm65_kit_top_assembly.stl
183.8 x 140.8 x 18.9

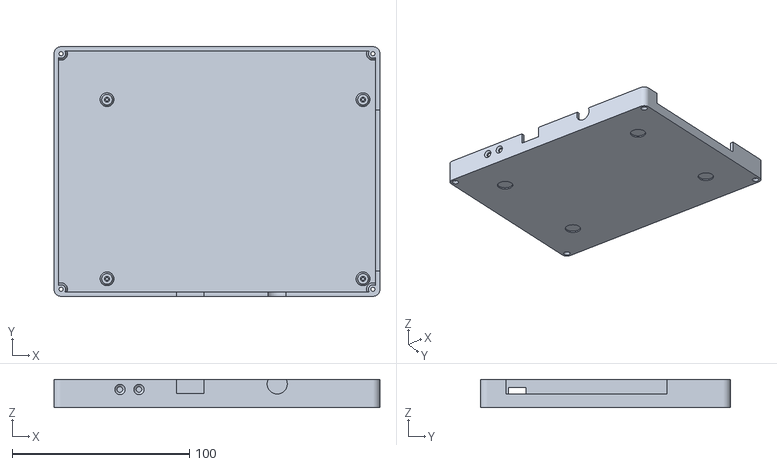
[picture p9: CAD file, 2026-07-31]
enclosure/build/rm65_kit_bottom.stl
183.8 x 140.8 x 16.0

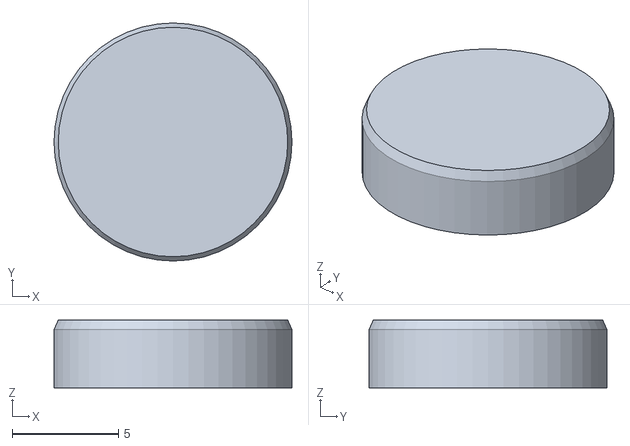
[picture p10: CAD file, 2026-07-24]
enclosure/build/rm65_kit_foot_pad.stl
11.2 x 11.2 x 3.20

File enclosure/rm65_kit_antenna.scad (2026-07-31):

/*
  Antenna bulkhead bosses, cutouts and feedline anchors for RM65 KIT shell.
  Included by rm65_kit_enclosure.scad; depends on parent globals.
*/

// ========== 分区：公开 API ==========
function antenna_rear_enabled() =
    antenna_layout == "rear_spread"
    || antenna_layout == "rear_and_left";

function antenna_left_enabled() =
    antenna_layout == "rear_and_left"
    || antenna_layout == "left_spread";

module antenna_mount_bosses() {
    if (antenna_holes_enabled) {
        if (antenna_rear_enabled())
            for (x = antenna_rear_x)
                translate([x - antenna_mount_pad_width / 2,
                           outer_y - wall - antenna_mount_reinforce_depth,
                           antenna_z - antenna_mount_pad_height / 2])
                    cube([antenna_mount_pad_width,
                          antenna_mount_reinforce_depth + 0.20,
                          antenna_mount_pad_height]);
        if (antenna_left_enabled())
            for (y = antenna_left_y)
                translate([wall - 0.20,
                           y - antenna_mount_pad_width / 2,
                           antenna_z - antenna_mount_pad_height / 2])
                    cube([antenna_mount_reinforce_depth + 0.20,
                          antenna_mount_pad_width,
                          antenna_mount_pad_height]);
    }
}

module antenna_bulkhead_cutout_rear(x) {
    translate([x, outer_y + 1, antenna_z])
        rotate([90, 0, 0])
            cylinder(d = antenna_hole_diameter, h = wall + 2);
    // Exterior relief: effective panel thickness drops by 1 mm so more male
    // thread protrudes for the whip antenna knuckle.
    translate([x, outer_y + 0.05, antenna_z])
        rotate([90, 0, 0])
            cylinder(d = antenna_exterior_relief_diameter,
                     h = antenna_exterior_protrusion_relief + 0.05);
    translate([x,
               outer_y - wall
               - antenna_mount_reinforce_depth - 0.1,
               antenna_z])
        rotate([-90, 0, 0])
            cylinder(
                d = antenna_nut_across_flats / cos(30),
                h = antenna_nut_depth + 0.1,
                $fn = 6);
}

module antenna_bulkhead_cutout_left(y) {
    translate([-1, y, antenna_z])
        rotate([0, 90, 0])
            cylinder(d = antenna_hole_diameter, h = wall + 2);
    translate([-0.05, y, antenna_z])
        rotate([0, 90, 0])
            cylinder(d = antenna_exterior_relief_diameter,
                     h = antenna_exterior_protrusion_relief + 0.05);
    translate([wall + antenna_mount_reinforce_depth + 0.1,
               y, antenna_z])
        rotate([0, -90, 0])
            cylinder(
                d = antenna_nut_across_flats / cos(30),
                h = antenna_nut_depth + 0.1,
                $fn = 6);
}

module antenna_cutouts() {
    if (antenna_holes_enabled) {
        if (antenna_rear_enabled())
            for (x = antenna_rear_x)
                antenna_bulkhead_cutout_rear(x);
        if (antenna_left_enabled())
            for (y = antenna_left_y)
                antenna_bulkhead_cutout_left(y);
        if (antenna_layout == "legacy_row")
            for (x = antenna_x)
                translate([x, outer_y + 1, antenna_z])
                    rotate([90, 0, 0])
                        cylinder(d = antenna_hole_diameter, h = wall + 2);
    }
}

module antenna_feed_anchor_pair(anchor_x, anchor_y, along_y) {
    // U-shaped tie bridge; along_y=true places it on the rear wall.
    z0 = split_z + 2.0;
    if (along_y) {
        y0 = anchor_y;
        for (dx = [-antenna_feed_anchor_width / 2,
                   antenna_feed_anchor_width / 2 - 1.5])
            translate([anchor_x + dx, y0, z0])
                cube([1.5, antenna_feed_anchor_depth,
                      antenna_feed_anchor_height]);
        translate([anchor_x - antenna_feed_anchor_width / 2,
                   y0,
                   z0 + antenna_feed_anchor_height])
            cube([antenna_feed_anchor_width,
                  antenna_feed_anchor_depth, 1.5]);
    } else {
        x0 = anchor_x;
        for (dy = [-antenna_feed_anchor_width / 2,
                   antenna_feed_anchor_width / 2 - 1.5])
            translate([x0, anchor_y + dy, z0])
                cube([antenna_feed_anchor_depth, 1.5,
                      antenna_feed_anchor_height]);
        translate([x0,
                   anchor_y - antenna_feed_anchor_width / 2,
                   z0 + antenna_feed_anchor_height])
            cube([antenna_feed_anchor_depth,
                  antenna_feed_anchor_width, 1.5]);
    }
}

module antenna_feedline_anchors() {
    // U-bridges fused to the inner wall, laterally offset so each M6 bulkhead
    // can pass straight from inside to outside before the pigtail is dressed.
    if (antenna_holes_enabled) {
        if (antenna_rear_enabled())
            for (i = [0 : len(antenna_rear_x) - 1]) {
                x = antenna_rear_x[i];
                direction = i < 2 ? 1 : (i > 2 ? -1 : 1);
                antenna_feed_anchor_pair(
                    x + direction * antenna_feed_anchor_lateral_offset,
                    outer_y - wall - antenna_feed_anchor_depth + 0.4,
                    true);
            }
        if (antenna_left_enabled())
            for (i = [0 : len(antenna_left_y) - 1]) {
                y = antenna_left_y[i];
                direction = i < 2 ? 1 : (i > 2 ? -1 : 1);
                antenna_feed_anchor_pair(
                    wall + 0.4,
                    y + direction * antenna_feed_anchor_lateral_offset,
                    false);
            }
    }
}

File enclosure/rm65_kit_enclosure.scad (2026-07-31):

/*
  HiLink RM65 KIT enclosure — measured HLK-AX3000-KIT V1.0 revision

  XY data is taken from the official 2024-12-05 PcbDoc. Interface Z and
  protrusion values are measured from the delivered V1.0 board. Small FDM
  fit allowances remain printer/material dependent and should be verified
  with the supplied test-coupon workflow before a long final print.
*/

// ========== 分区：导入/依赖 ==========
// Module bodies resolve parent globals at call time, so includes may precede
// the parameter block.
include <rm65_kit_antenna.scad>
include <rm65_kit_shell_parts.scad>

// ========== 分区：常量/配置 ==========
// Export target: "bottom", "top", "top_assembly", "foot_pad", or "assembly".
part = "assembly";

pcb_x = 152.0038;              // official PcbDoc outline
pcb_y = 109.0000;
pcb_thickness = 1.6;
wall = 2.4;
floor_thickness = 2.4;
top_thickness = 2.4;
pcb_side_clearance = 3.5;      // front/right plug tunnel; clears PCB M2 bosses
// Left bay: IPX pigtails are too short for an all-rear layout; Dupont/header
// side (opposite RJ45 mouths) gets its own inside-out bulkhead service bay.
left_service_extension = 20.0;
rear_service_extension = 20.0;// keep rear bay; original rear ports remain usable
clearance_below_pcb = 4.0;     // 2.5 mm solder pins + 1.5 mm safety margin
clearance_above_pcb = 19.5;    // 17 mm heatsink + 2.5 mm safety margin

// Official PcbDoc J8/J5/J6/J7 mounting-pad centres, relative to the board
// outline lower-left. The plated physical holes are 125 mil = 3.175 mm.
pcb_holes_enabled = true;
pcb_holes = [
    [4.0008, 4.0053],          // J8 lower-left
    [3.9879, 105.0016],        // J5 upper-left
    [148.3238, 4.0000],        // J6 lower-right
    [148.3238, 105.0000]       // J7 upper-right
];
pcb_mount_hole_diameter = 3.175;
pcb_screw_nominal = 2.0;       // user-selected M2 PCB fixing
pcb_pilot_diameter = 1.7;      // M2 self-tapping pilot in printed boss
pcb_standoff_outer_diameter = 6.0;
pcb_standoff_height = clearance_below_pcb;
pcb_guide_diameter = 2.85;     // centres the 3.175 mm PCB hole
pcb_guide_height = 1.0;
pcb_screw_recommendation = "M2x6 pan-head, self-tapping into 1.7 mm pilot";

// External plug envelopes retained as assembly documentation.
dc_plug_grip_diameter = 18.0;  // external hand/finger access envelope
dc_cable_bend_clearance = 35.0;// free space outside panel; documentation only

// ---------- PCB-DOC XY INTERFACE CUTOUT CANDIDATE ----------
// XY is official PcbDoc data. Z is derived from the measured board using the
// PCB top surface as datum. Each interface has its own height; there is no
// longer one guessed global Z centre.
interface_cutouts_enabled = true;
pcb_bottom_z = floor_thickness + clearance_below_pcb;
pcb_top_z = pcb_bottom_z + pcb_thickness;

rj45_y = [15.64, 30.89, 46.14, 61.39, 75.86, 91.74];
rj45_port_width = 14.6;
rj45_opening_y0 = rj45_y[0] - rj45_port_width / 2;
rj45_opening_y1 = rj45_y[len(rj45_y) - 1] + rj45_port_width / 2;
rj45_opening_height = 14.6;    // 13.8 measured + 0.4 mm each side
rj45_z_center = pcb_top_z + 13.8 / 2;
rj45_protrusion = 2.0;

switch_x = [11.29, 22.03];     // GPIO_RST, SYS_RST
switch_labels = ["GPIO_RST", "SYS_RST"];
switch_y = 1.94;               // component reference; front-wall hole uses X
switch_tool_diameter = 3.2;
switch_recess_diameter = 6.0;
switch_recess_depth = 1.2;
switch_z_center = pcb_top_z + 4.5 / 2;
switch_protrusion = 0.5;
usb_reference_x = 38.40;      // official footprint/model insertion origin, not mouth centre
usb_mouth_offset_x = 12.60;   // delivered board: mouth spans X=43.5..58.5, centre=51.0
usb_x = usb_reference_x + usb_mouth_offset_x;
usb_y = -2.48;                 // component reference; front-wall hole uses X
usb_opening_width = 15.6;
usb_opening_height = 8.3;      // measured 0.5..8.0 + 0.4 mm vertical clearance
usb_z_center = pcb_top_z + (0.5 + 8.0) / 2;
usb_protrusion = 2.5;
dc_x = 99.95;
dc_y = 6.25;                   // component reference; front-wall hole uses X
dc_shell_opening_diameter = 11.4;
dc_z_center = pcb_top_z + 10.8 / 2;
dc_protrusion = 1.2;

// USB-TTL Type-C on the left wall. The PcbDoc reference sits at one end of
// the 8.636 mm connector outline, so use the outline/mouth centre instead.
typec_reference_y = 19.1213;
typec_mouth_offset_y = -4.3540;
typec_y = typec_reference_y + typec_mouth_offset_y;
typec_x = 5.9372;
typec_opening_width = 10.0;    // along PCB Y, includes FDM clearance
typec_opening_height = 3.8;    // measured 3.0 mm + 0.4 mm each side
typec_z_center = pcb_top_z + 3.0 / 2;
typec_protrusion = 0.8;

led_x = [15.01, 21.18, 27.34, 33.51, 39.67,
         45.84, 52.07, 58.23, 64.40];
led_y = 102.06;                // component reference; rear-wall hole uses X
led_shell_hole_diameter = 3.6;
led_z_center = pcb_top_z + 1.5;
led_guide_outer_diameter = 5.4;
led_guide_lower_z = pcb_top_z + 5.0; // stays above the photographed LED domes

// Package-B M6 bulkhead antenna connector (~M8 panel idiom / ~8 mm-AF nut).
// Printed inner thickening captures the hex nut; exterior stays circular.
antenna_holes_enabled = true;
antenna_hole_diameter = 6.5;   // M6 thread + 0.5 mm FDM assembly allowance
// Ten M6 holes remain (rear 5 + left 5). Only five get whips; see RF plan below.
antenna_layout = "rear_and_left";
antenna_z = 22.0;              // nut envelope stays clear of roof and split
antenna_pivot_keepout_radius = 12.0; // mechanical sweep only; not RF spacing
antenna_x = [22, 49, 76, 103, 130]; // legacy rear-row option
antenna_nut_across_flats = 8.3;
antenna_nut_depth = 3.2;
antenna_insertion_envelope_length = 23.0; // inside-out service envelope
antenna_insertion_envelope_diameter = 10.0;
antenna_mount_pad_width = 13.0;
antenna_mount_pad_height = 12.0; // lower edge lands exactly on the split plane
antenna_mount_reinforce_depth = 3.4;
antenna_feed_anchor_width = 8.0;
antenna_feed_anchor_depth = 3.0;
antenna_feed_anchor_height = 6.0;
antenna_feed_anchor_slot = 3.0;
antenna_feed_anchor_lateral_offset = 10.0; // keeps the insertion axis open
// Exterior counterbore so more male thread sticks out for whip antennas.
antenna_exterior_protrusion_relief = 1.0;
antenna_exterior_relief_diameter = 9.0;

// ----- RF plan (2.4G×2 + 5G×3), IPX reach: rear-left 3 + any left 5 -----
// Free-space targets: λ24≈125 mm (λ/2≈62.5); λ5≈55 mm @5.5 GHz (λ/2≈27.5).
// 2.4G on orthogonal walls at max reach; 5G triad with ≥λ/2 mutual spacing.
antenna_rf_lambda_24 = 125.0;
antenna_rf_lambda_5 = 55.0;
antenna_whip_length = 85.0;    // preview / keepout documentation only

// ---------- PRINT / FIT PARAMETERS ----------
// PCB shifts right by left_service_extension; left bay is empty service volume.
pcb_origin_x = wall + left_service_extension + pcb_side_clearance;
pcb_origin_y = wall + pcb_side_clearance;
corner_radius = 4.0;
lid_overlap = 5.0;
fit_clearance = 0.30;         // per side; tune for the printer/material
lid_skirt_thickness = 1.2;    // inner skirt; avoids overlapping outer walls
lid_skirt_root_height = 4.0;  // gradual ramp; avoids a brittle 90-degree neck
lid_skirt_wall_overlap = 0.60;// outward ramp embeds into the cap side wall
interface_cut_depth = wall + fit_clearance + lid_skirt_thickness + 2.0;
panel_fit_clearance = 0.35;

foot_recess_diameter = 11.0;
foot_recess_depth = 1.0;       // leaves 1.4 mm of the 2.4 mm floor
foot_recess_mouth_diameter = 11.4;
foot_pad_diameter = 11.2;      // 0.2 mm TPU interference vs recess
foot_pad_total_height = 3.2;
foot_pad_insert_height = 1.0;
foot_pad_tip_diameter = 10.8;  // lead-in chamfer, no internal undercut
bottom_foot_inset = 30.0;      // clears shell screws and PCB bosses

case_screw_nominal = 2.0;      // M2 countersunk enclosure screws
case_screw_clearance = 2.3;    // reference-project fit
case_screw_pilot = 1.7;
case_screw_head_diameter = 5.0;
case_screw_head_depth = 1.8;
case_post_outer_diameter = 5.0;
case_post_reinforce_diameter = 7.5;
case_post_reinforce_height = 2.5;
boss_rib_thickness = 1.6;
boss_rib_length = 5.0;
case_post_inset = 4.0;         // corner-wall post, clear of official PCB bosses

vent_enabled = true;
vent_slot_width = 3.0;
vent_slot_length = 38.0;
vent_rows = 4;
vent_columns = 3;
vent_pitch_x = 45.0;
vent_pitch_y = 9.0;

brand_enabled = true;
brand_font = "Liberation Sans:style=Bold";
brand_bridge = 1.0;            // stencil bridge retains O/R/A/o counters
brand_line1 = "NORMAN";
brand_line2 = "Router V1.2.0";
brand_line1_size = 11.5;       // larger strokes for reliable FDM through-cuts
brand_line2_size = 7.2;
// Front/top band (low Y, above the USB/DC wall); clear of centre vent field.
brand_line1_y = 28.0;
brand_line2_y = 16.0;

// Preview-only separation. Ignored by individual STL exports.
assembly_gap = 0.0;
$fn = 48;
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

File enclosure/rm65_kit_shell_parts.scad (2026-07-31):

/*
  Shared shell primitives, mounts, feet and interface cutouts for RM65 KIT.
  Included by rm65_kit_enclosure.scad; depends on parent globals.
*/

// ========== 分区：公开 API ==========
module rounded_box(size, r) {
    hull()
        for (x = [r, size[0] - r], y = [r, size[1] - r])
            translate([x, y, 0]) cylinder(r = r, h = size[2]);
}

module local_rib_cross(h) {
    // Used only for free-standing PCB supports where no nearby wall exists.
    for (a = [0, 90])
        rotate([0, 0, a])
            translate([-boss_rib_length / 2, -boss_rib_thickness / 2, 0])
                cube([boss_rib_length, boss_rib_thickness, h]);
}

module reinforced_post(h, hole_d) {
    difference() {
        union() {
            cylinder(d1 = case_post_reinforce_diameter,
                     d2 = case_post_outer_diameter,
                     h = min(case_post_reinforce_height, h));
            if (h > case_post_reinforce_height)
                translate([0, 0, case_post_reinforce_height])
                    cylinder(d = case_post_outer_diameter,
                             h = h - case_post_reinforce_height);
        }
        translate([0, 0, -0.1])
            cylinder(d = hole_d, h = h + 0.2);
    }
}

module ribs_to_nearest_walls(x, y, h, z_start = 0) {
    // Each corner boss is tied only to its two nearest inner walls.
    // The ribs remain inside the enclosure and make a direct wall/boss load path.
    rib_h = min(case_post_reinforce_height, h);
    x_left = x < outer_x / 2;
    y_front = y < outer_y / 2;
    // 0.20 mm overlap prevents merely coplanar contact after STL tessellation.
    x_len = x_left ? x - wall + 0.20 : outer_x - wall - x + 0.20;
    y_len = y_front ? y - wall + 0.20 : outer_y - wall - y + 0.20;

    translate([x_left ? -x_len : 0, -boss_rib_thickness / 2, z_start])
        cube([x_len, boss_rib_thickness, rib_h]);
    translate([-boss_rib_thickness / 2, y_front ? -y_len : 0, z_start])
        cube([boss_rib_thickness, y_len, rib_h]);
}

module case_post_locations(h, hole_d) {
    for (x = [case_post_inset, outer_x - case_post_inset],
         y = [case_post_inset, outer_y - case_post_inset]) {
        translate([x, y, 0]) reinforced_post(h, hole_d);
        translate([x, y, 0]) ribs_to_nearest_walls(x, y, h);
    }
}

module top_reinforced_post(h, hole_d) {
    reinforce_h = min(case_post_reinforce_height, h);
    difference() {
        union() {
            if (h > reinforce_h)
                cylinder(d = case_post_outer_diameter,
                         h = h - reinforce_h);
            // Flare is at the roof end, not at the split-plane end.
            translate([0, 0, h - reinforce_h])
                cylinder(d1 = case_post_outer_diameter,
                         d2 = case_post_reinforce_diameter,
                         h = reinforce_h);
        }
        translate([0, 0, -0.1])
            cylinder(d = hole_d, h = h + 0.2);
    }
}

module top_case_post_locations(z0, h) {
    for (x = [case_post_inset, outer_x - case_post_inset],
         y = [case_post_inset, outer_y - case_post_inset]) {
        translate([x, y, z0])
            top_reinforced_post(h, case_screw_pilot);
        // Ribs occupy only the roof-side reinforced zone and meet both
        // nearest top-shell inner walls. Nothing protrudes below z0.
        translate([x, y, z0])
            ribs_to_nearest_walls(x, y, h,
                                  h - min(case_post_reinforce_height, h));
    }
}

module pcb_standoffs() {
    if (pcb_holes_enabled)
        for (p = pcb_holes)
            translate([
                pcb_origin_x + p[0],
                pcb_origin_y + p[1],
                floor_thickness - 0.20
            ])
                difference() {
                    union() {
                        cylinder(d1 = pcb_standoff_outer_diameter + 2.0,
                                 d2 = pcb_standoff_outer_diameter,
                                 h = min(2.2, pcb_standoff_height + 0.2));
                        if (pcb_standoff_height > 2.0)
                            translate([0, 0, 2.2])
                                cylinder(d = pcb_standoff_outer_diameter,
                                         h = pcb_standoff_height - 2.0);
                        local_rib_cross(min(2.2, pcb_standoff_height + 0.2));
                        translate([0, 0, pcb_standoff_height + 0.2])
                            cylinder(d1 = pcb_guide_diameter,
                                     d2 = pcb_guide_diameter,
                                     h = pcb_guide_height);
                    }
                    translate([0, 0, -0.1])
                        cylinder(d = pcb_pilot_diameter,
                                 h = pcb_standoff_height + 0.2
                                     + pcb_guide_height + 0.2);
                }
}

module foot_recesses() {
    for (x = [bottom_foot_inset, outer_x - bottom_foot_inset],
         y = [bottom_foot_inset, outer_y - bottom_foot_inset])
        translate([x, y, -0.1]) {
            cylinder(d1 = foot_recess_mouth_diameter,
                     d2 = foot_recess_diameter,
                     h = min(0.45, foot_recess_depth));
            translate([0, 0, min(0.45, foot_recess_depth) - 0.01])
                cylinder(d = foot_recess_diameter,
                         h = foot_recess_depth
                             - min(0.45, foot_recess_depth) + 0.12);
        }
}

module foot_pad() {
    exposed_h = foot_pad_total_height - foot_pad_insert_height;
    union() {
        cylinder(d = foot_pad_diameter, h = exposed_h);
        translate([0, 0, exposed_h])
            cylinder(d = foot_pad_diameter,
                     h = max(0.1, foot_pad_insert_height - 0.45));
        translate([0, 0, foot_pad_total_height - 0.45])
            cylinder(d1 = foot_pad_diameter,
                     d2 = foot_pad_tip_diameter, h = 0.45);
    }
}

module interface_cutouts() {
    if (interface_cutouts_enabled) {
        // Right wall: all six metal RJ45 faces are essentially contiguous on
        // the delivered board. One continuous opening avoids fragile FDM ribs.
        translate([outer_x + 1 - interface_cut_depth,
                   pcb_origin_y + rj45_opening_y0,
                   rj45_z_center - rj45_opening_height / 2])
            cube([interface_cut_depth,
                  rj45_opening_y1 - rj45_opening_y0,
                  rj45_opening_height]);

        // Bottom/front wall: GPIO_RST, SYS_RST, USB-A and DC.
        for (x = switch_x)
            translate([pcb_origin_x + x, interface_cut_depth - 1,
                       switch_z_center])
                rotate([90, 0, 0])
                    cylinder(d = switch_tool_diameter,
                             h = interface_cut_depth);
        // Exterior guide funnels keep both reset buttons finger-inaccessible.
        for (x = switch_x)
            translate([pcb_origin_x + x, switch_recess_depth,
                       switch_z_center])
                rotate([90, 0, 0])
                    cylinder(d1 = switch_tool_diameter,
                             d2 = switch_recess_diameter,
                             h = switch_recess_depth + 0.1);
        translate([pcb_origin_x + usb_x - usb_opening_width / 2,
                   -1,
                   usb_z_center - usb_opening_height / 2])
            cube([usb_opening_width, interface_cut_depth,
                  usb_opening_height]);
        translate([pcb_origin_x + dc_x, interface_cut_depth - 1,
                   dc_z_center])
            rotate([90, 0, 0])
                cylinder(d = dc_shell_opening_diameter,
                         h = interface_cut_depth);

        // Left wall: USB-TTL Type-C only. Maintenance pin headers stay closed.
        // Depth spans the left service bay so the mouth still reaches the PCB.
        translate([-1,
                   pcb_origin_y + typec_y - typec_opening_width / 2,
                   typec_z_center - typec_opening_height / 2])
            cube([typec_tunnel_depth + 1, typec_opening_width,
                  typec_opening_height]);

        // Top face near the rear edge: nine vertical LED/light-pipe windows.
        for (x = led_x)
            translate([pcb_origin_x + x, pcb_origin_y + led_y,
                       led_guide_lower_z - 0.1])
                cylinder(d = led_shell_hole_diameter,
                         h = outer_z - led_guide_lower_z + 0.2);
    }
}
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

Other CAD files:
enclosure/build/rm65_kit_top.stl

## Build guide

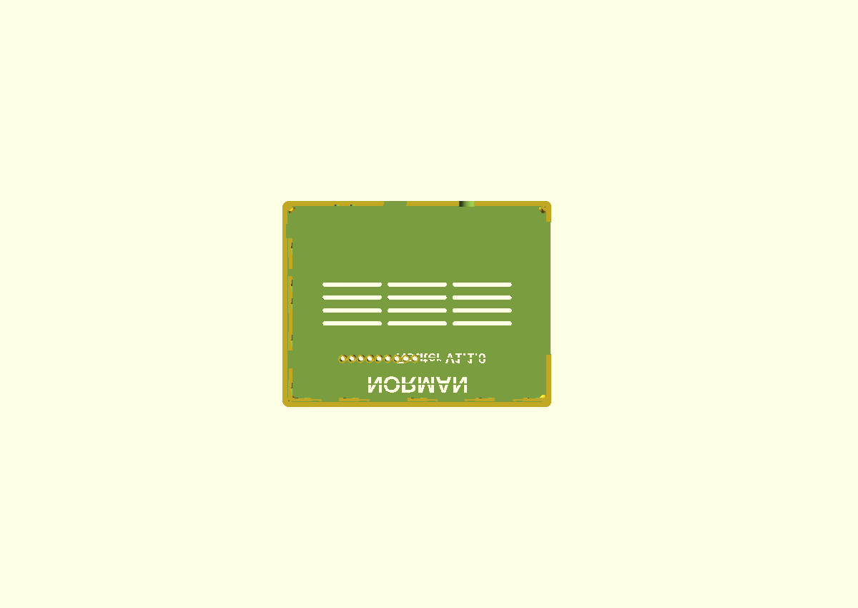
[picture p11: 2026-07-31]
enclosure/build/rm65_kit_top_inner.png

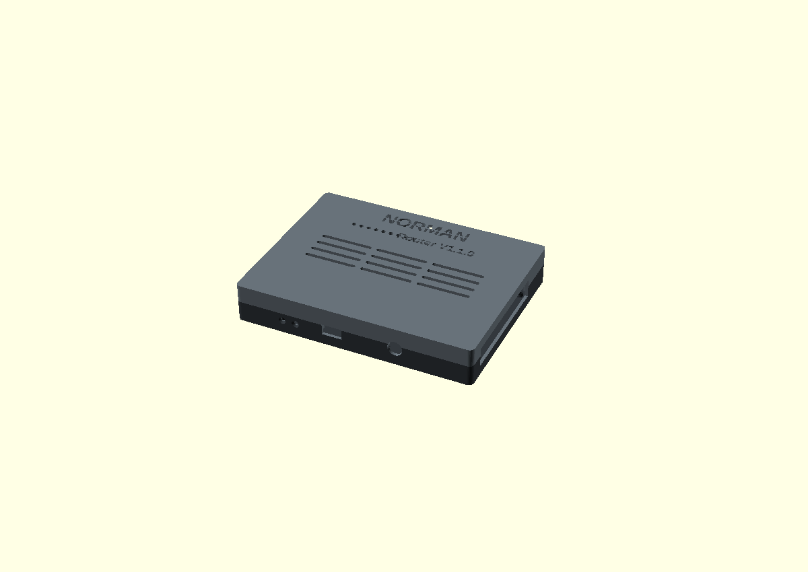
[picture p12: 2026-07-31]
enclosure/build/rm65_kit_preview.png

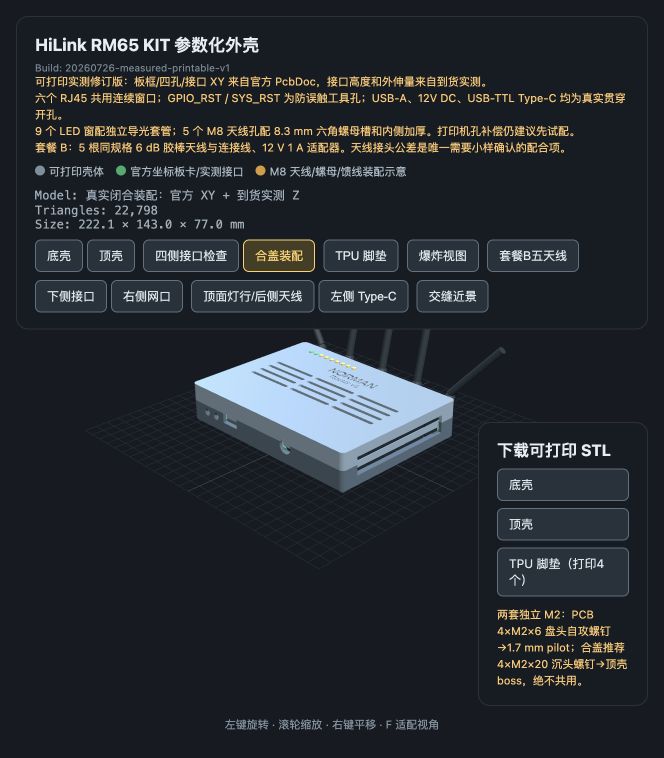
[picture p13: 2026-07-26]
enclosure/build/qa_measured_assembly.png

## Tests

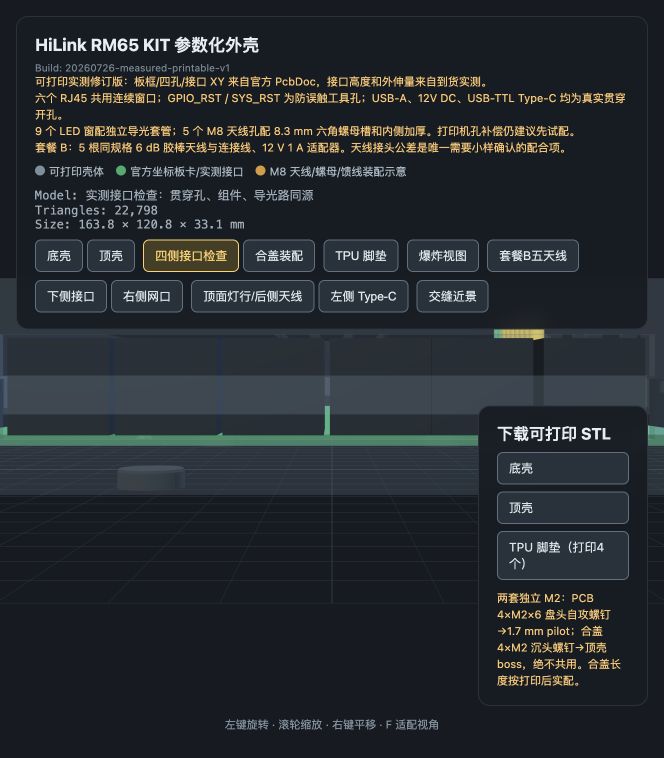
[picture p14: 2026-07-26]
enclosure/build/qa_measured_interfaces_right.png

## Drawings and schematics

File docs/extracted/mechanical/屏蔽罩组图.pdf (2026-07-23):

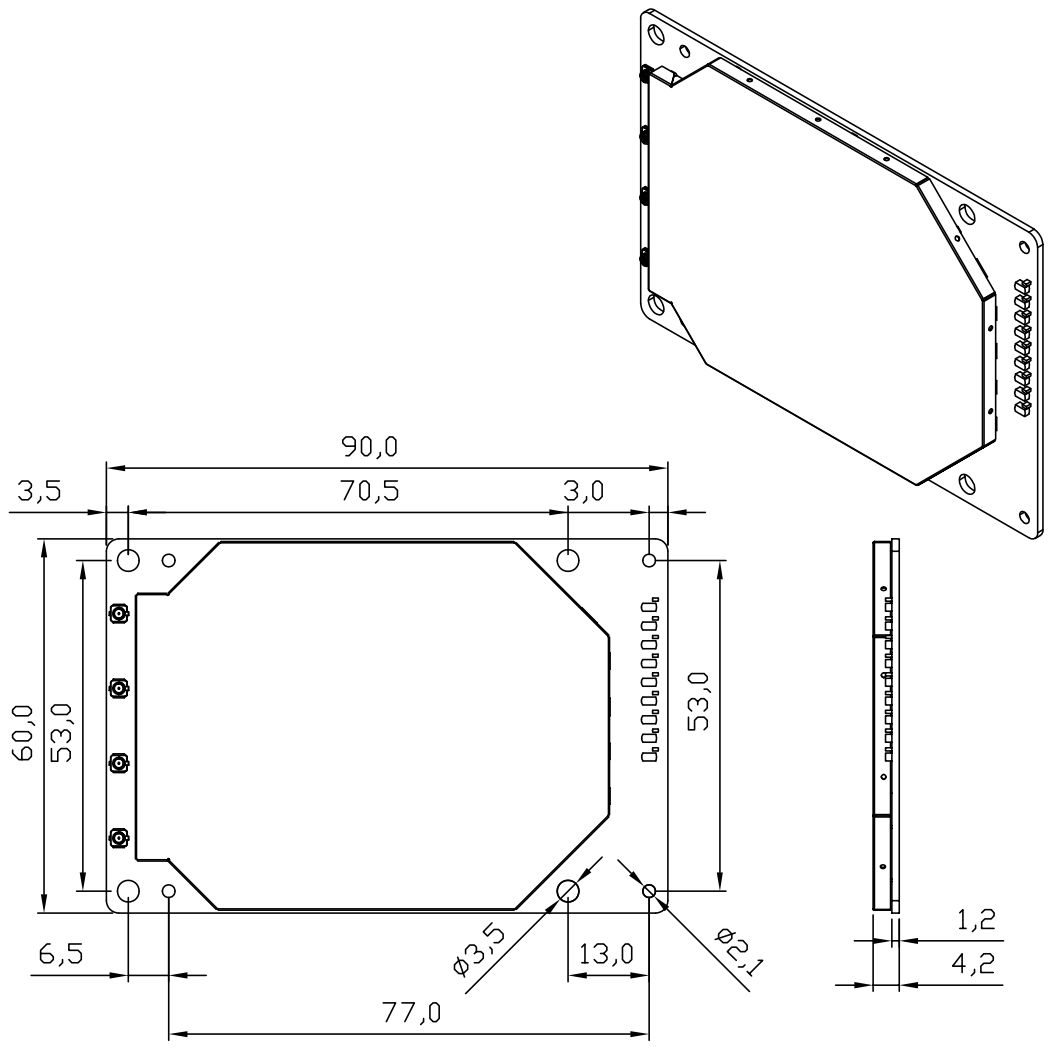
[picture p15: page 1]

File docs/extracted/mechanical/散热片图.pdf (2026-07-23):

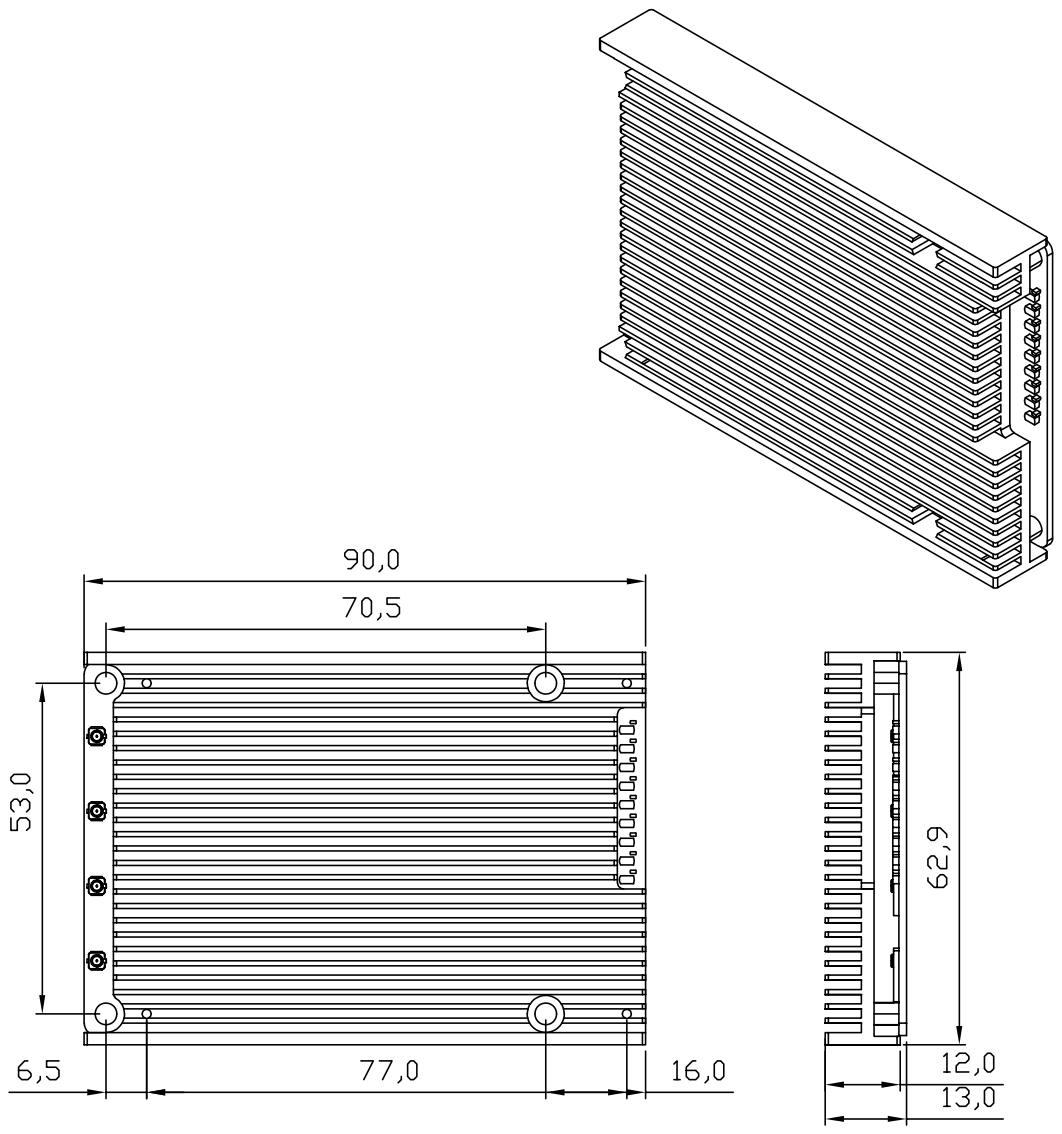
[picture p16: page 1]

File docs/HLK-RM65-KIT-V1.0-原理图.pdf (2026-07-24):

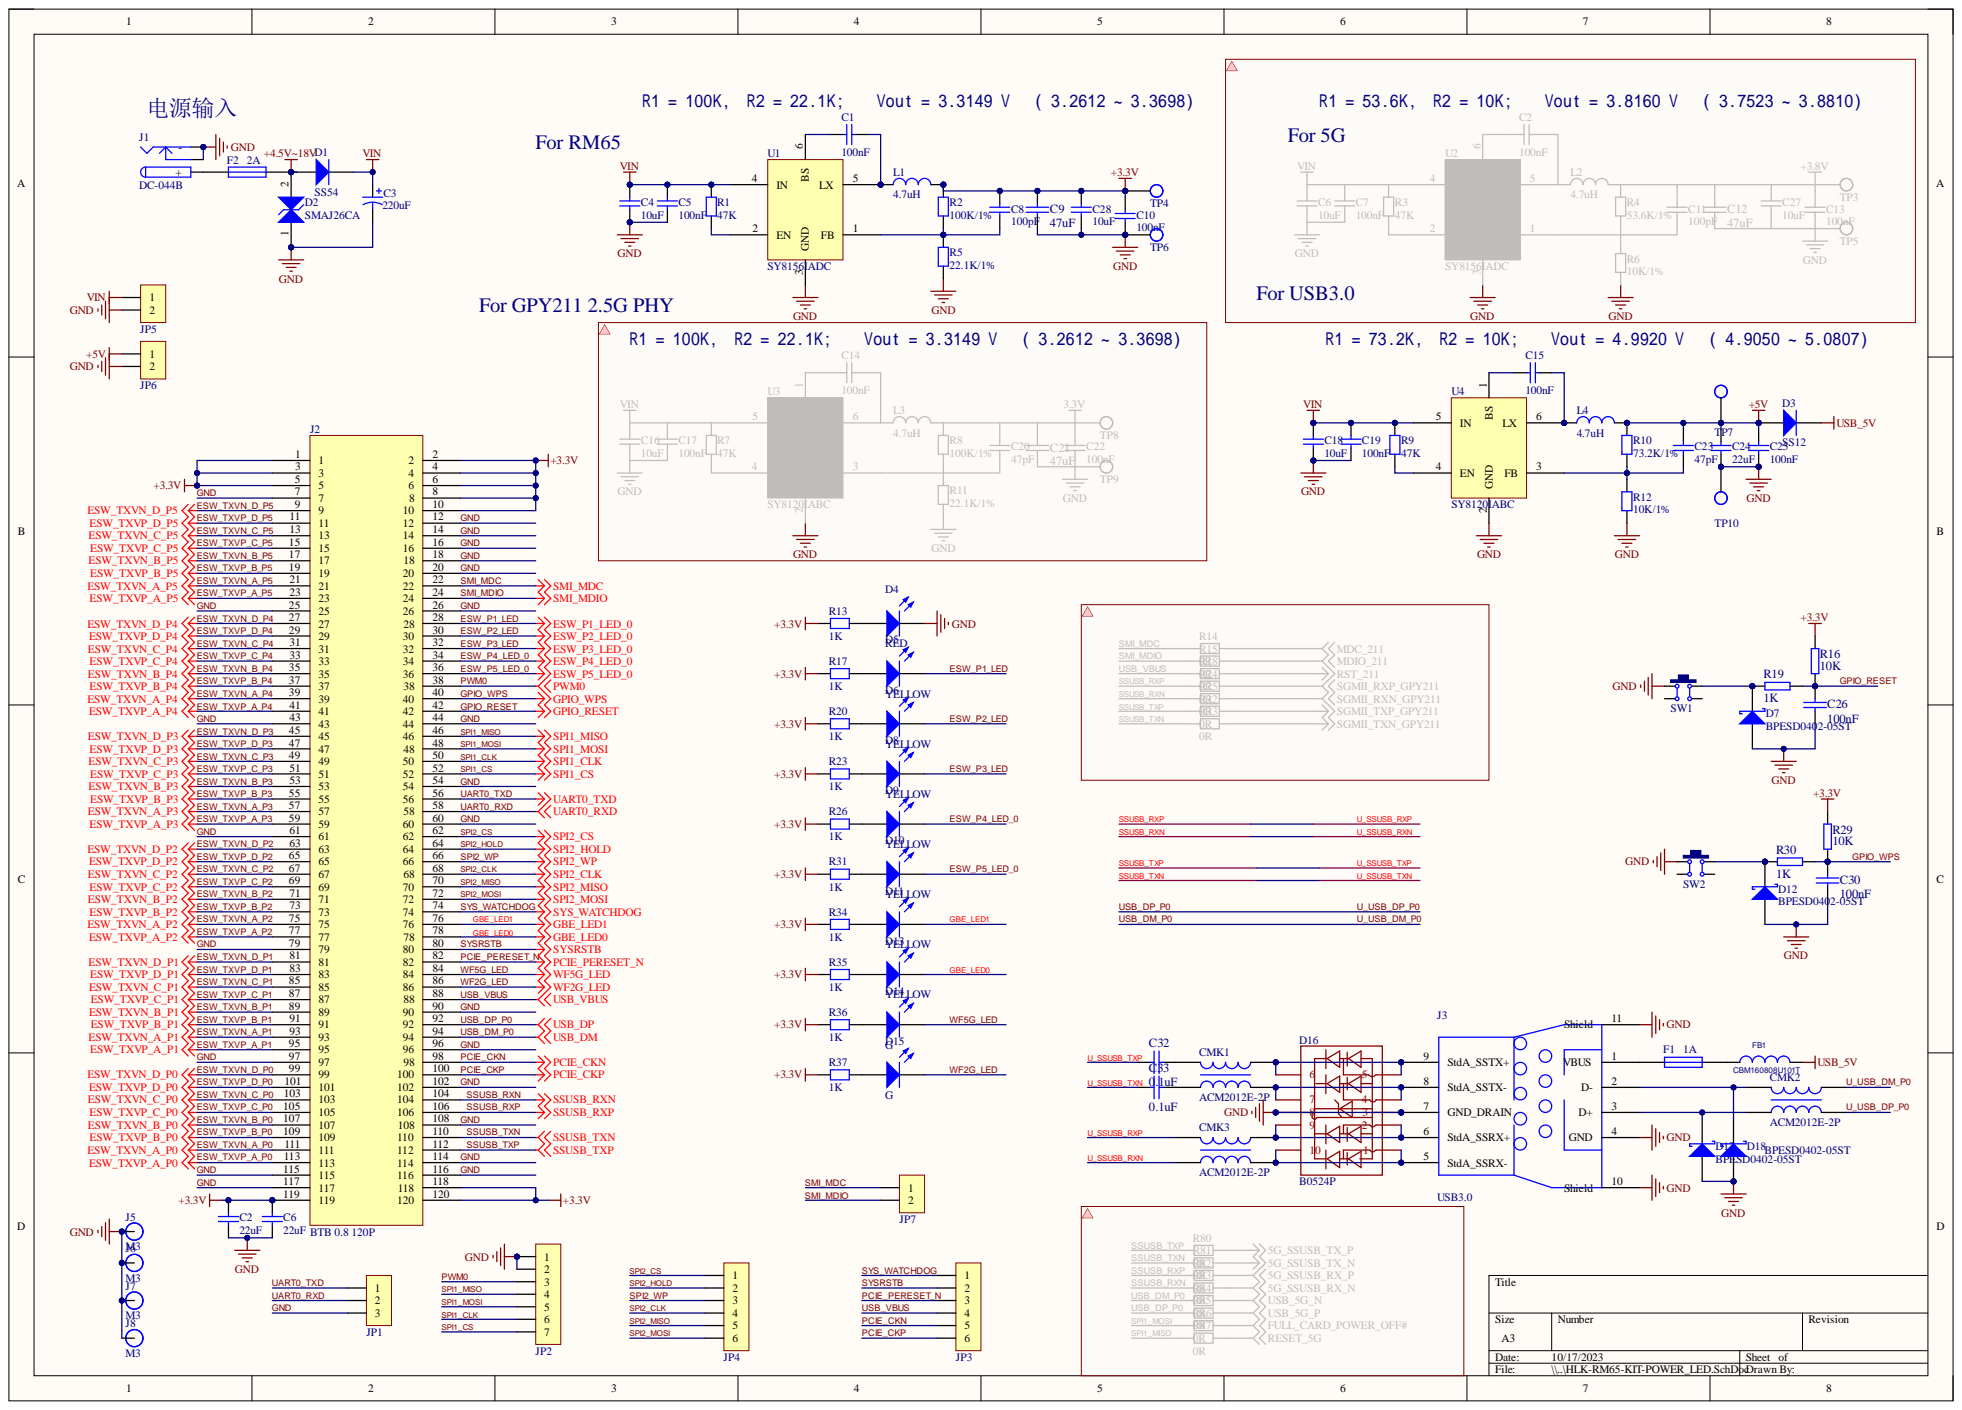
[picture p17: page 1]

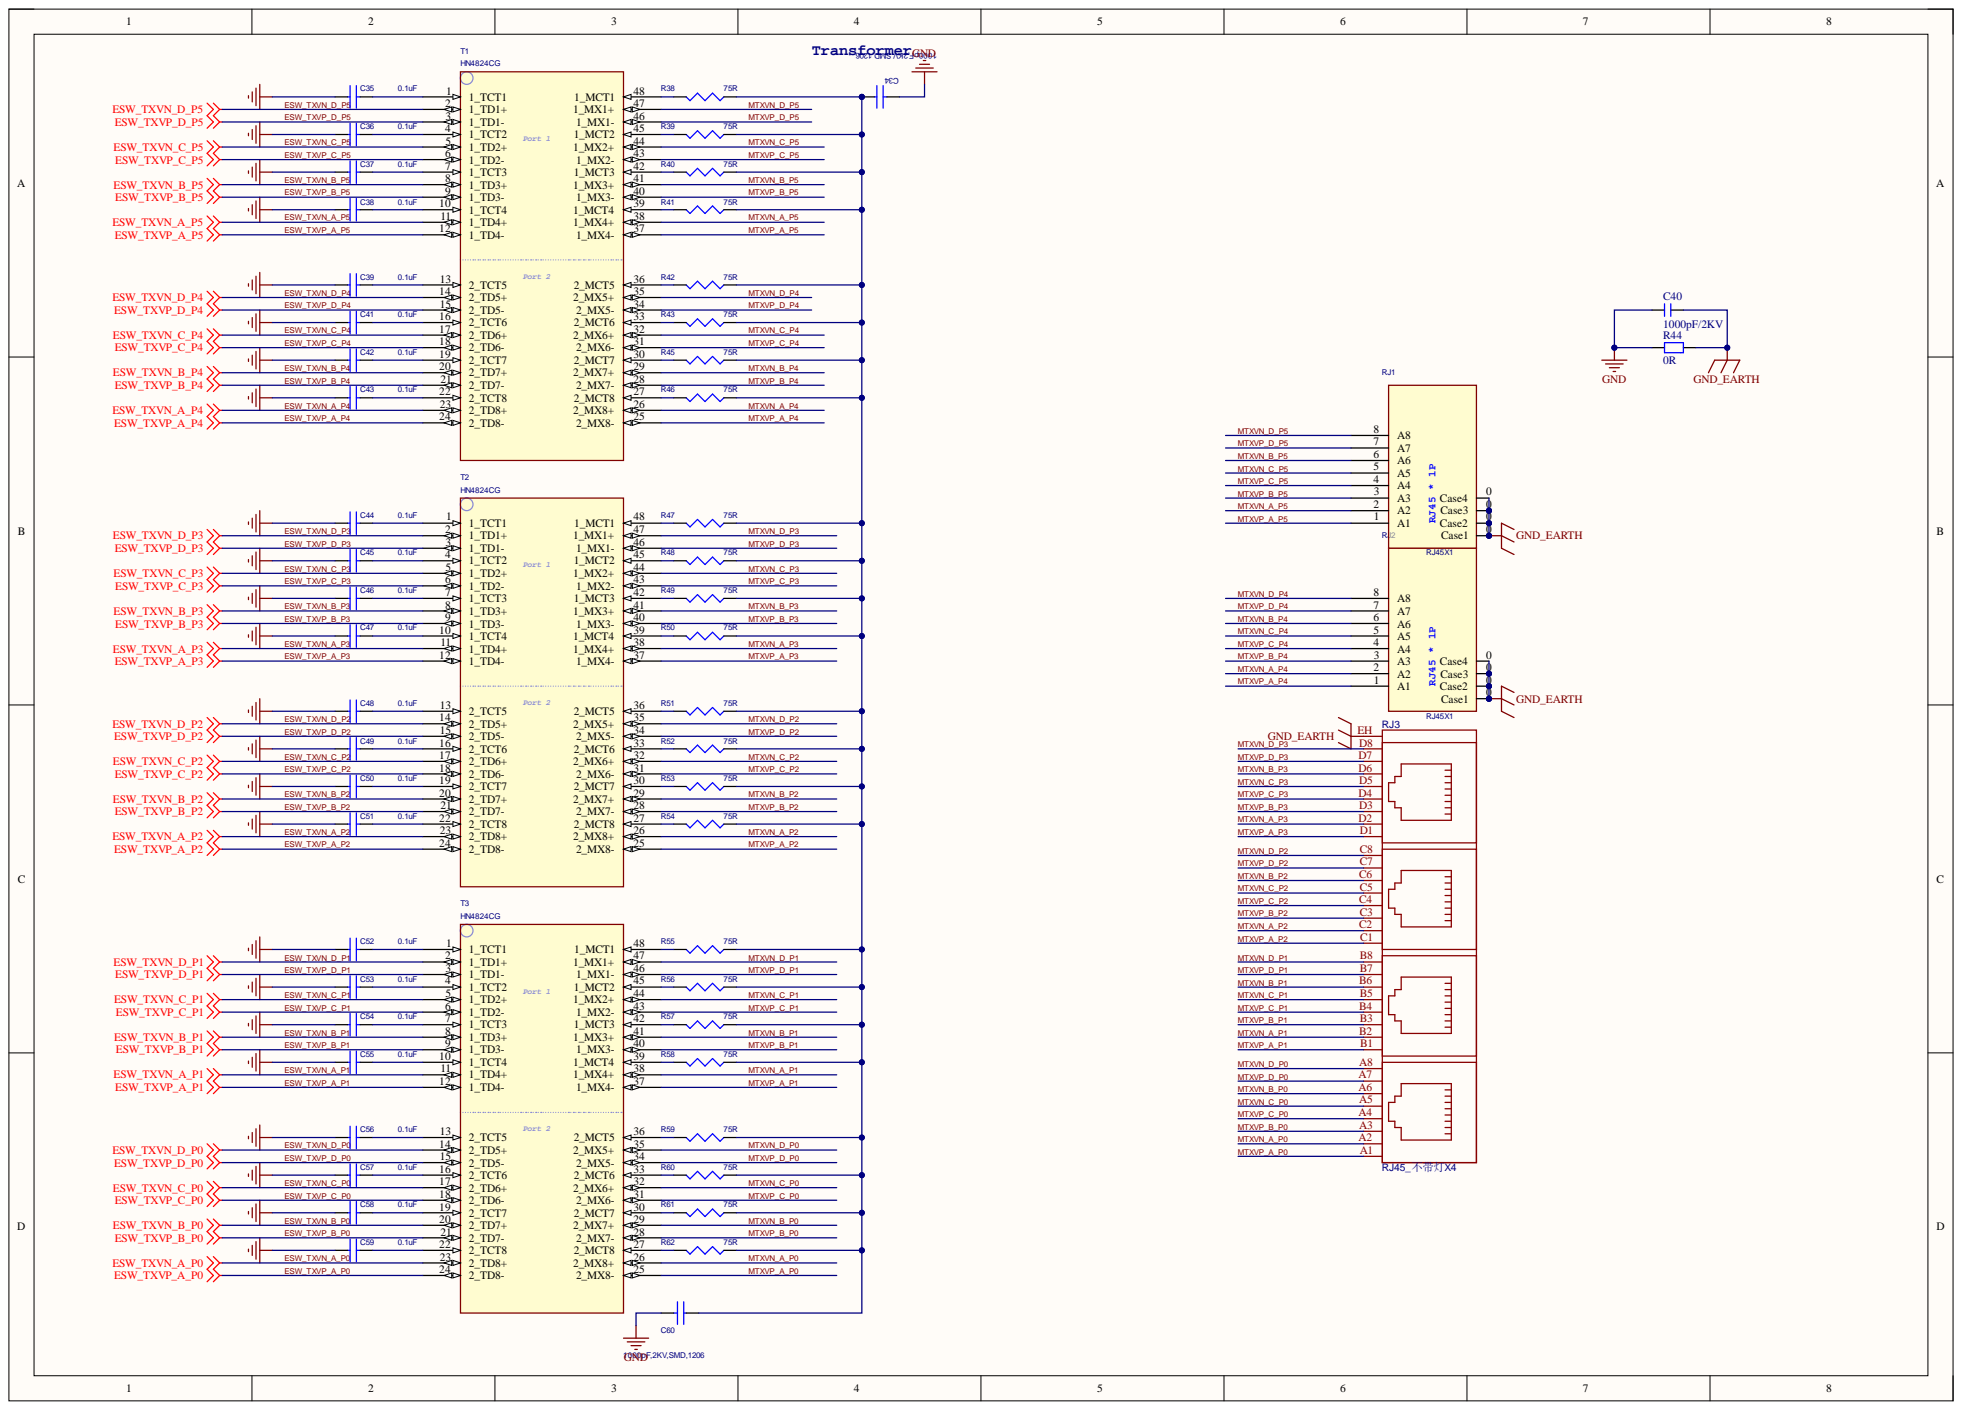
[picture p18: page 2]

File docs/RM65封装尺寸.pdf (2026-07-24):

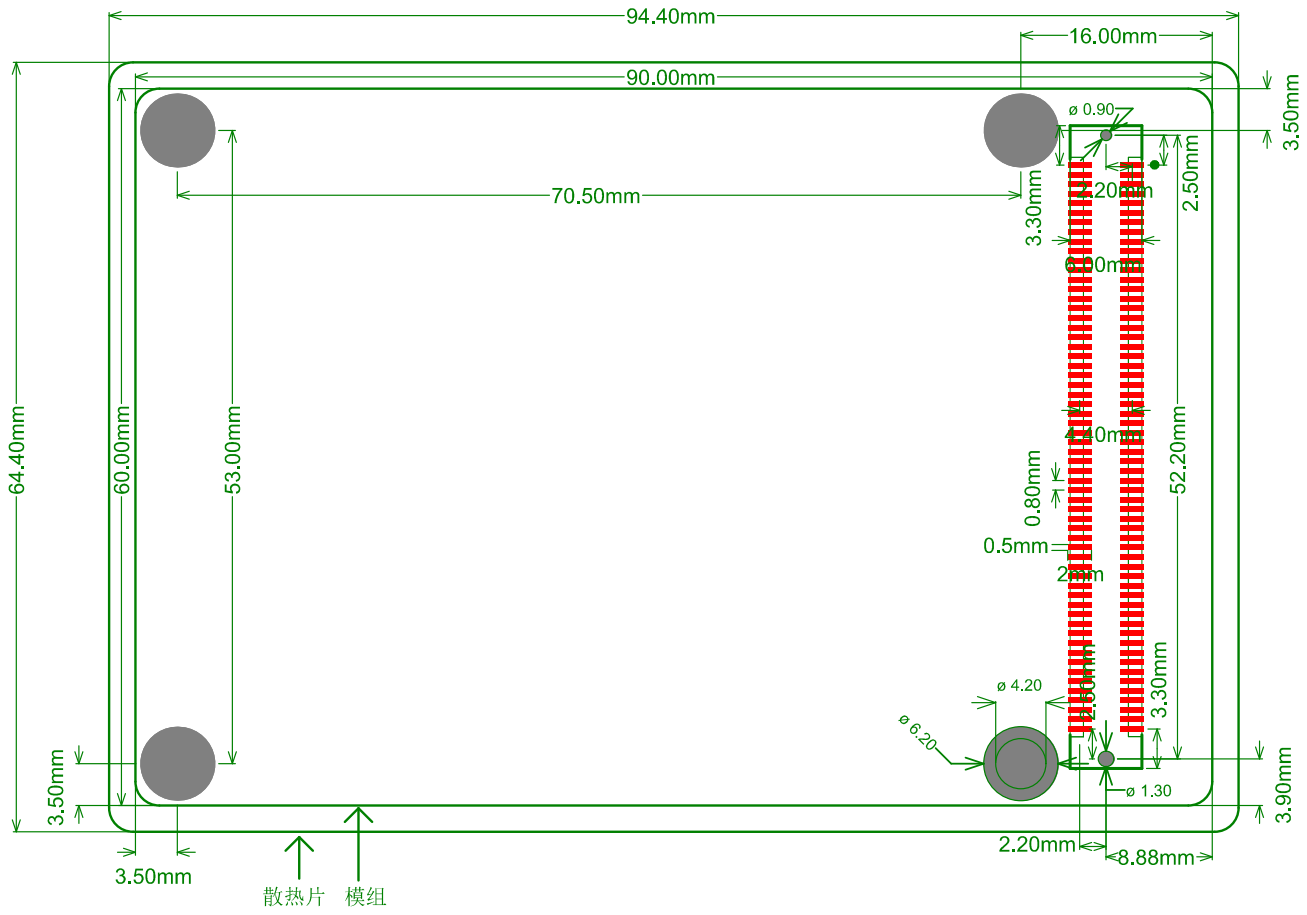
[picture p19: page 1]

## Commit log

2026-07-23 📦 docs: 归档 HLK-RM68 官方资料与家用路由可行性评估
    便于后续刷机与按 MAC 分流旁路分析架构落地，避免重复检索选型依据。
    [HLK-AX3000-KIT-POWER_LED.SchDoc, HLK-AX3000-KIT-RJ45.SchDoc, HLK-AX3000-KIT.PcbDoc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]
2026-07-23 📦 firmware: 归档 RM68 官方 OpenWrt SDK 来源与刷机说明
    官方未提供现成 .img，便于回来按百度 SDK/U-Boot 流程编译或向卖家索取镜像后刷机。
2026-07-23 🔧 fix: 将 gitee-rm68 刷机说明改为普通目录入库
    避免嵌套仓库导致克隆后缺少 U-Boot 刷机截图与说明正文。
2026-07-24 📦 docs: 归档 HLK-RM65 官方资料与 KIT 尺寸文件
    从海凌科下载页拉取规格书、结构件、KIT PCB/原理图与尺寸标注，便于后续外壳设计。
2026-07-24 📦 外壳：交付 RM65 参数化打印模型与装配预览
    [rm65_kit_bottom.stl, rm65_kit_enclosure.scad, rm65_kit_foot_pad.stl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]
2026-07-24 📦 完善 RM65 外壳接口与装配预览
    [rm65_kit_bottom.stl, rm65_kit_enclosure.scad, rm65_kit_foot_pad.stl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]
2026-07-26 📐 完成 RM65 实测可打印外壳
    [rm65_kit_bottom.stl, rm65_kit_enclosure.scad, rm65_kit_foot_pad.stl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]
2026-07-27 🔧 修正接口定位、天线舱与裙边加固
    [rm65_kit_bottom.stl, rm65_kit_enclosure.scad, rm65_kit_foot_pad.stl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]
2026-07-31 📐 左侧天线舱与前侧品牌字，修正 PCB/后孔对齐
    IPX 线偏短故主天线改到杜邦座侧；后壁五口相对板卡锁定；外丝面沉与预览缩放一并修好。
    [rm65_kit_antenna.scad, rm65_kit_bottom.stl, rm65_kit_enclosure.scad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]
2026-07-31 📡 固化 L 形 2.4G×2+5G×3 孔位，胶棒以竖直为主
    按 IPX 可达范围锁定五座装法与间距校验；多余孔留空，预览去掉夸张倾角。
    [rm65_kit_bottom.stl, rm65_kit_enclosure.scad, rm65_kit_top.stl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]
